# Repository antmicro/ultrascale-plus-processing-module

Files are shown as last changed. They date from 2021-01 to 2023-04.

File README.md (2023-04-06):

# Antmicro UltraScale+ Processing Module

Copyright (c) 2016-2023 [Antmicro](https://www.antmicro.com)



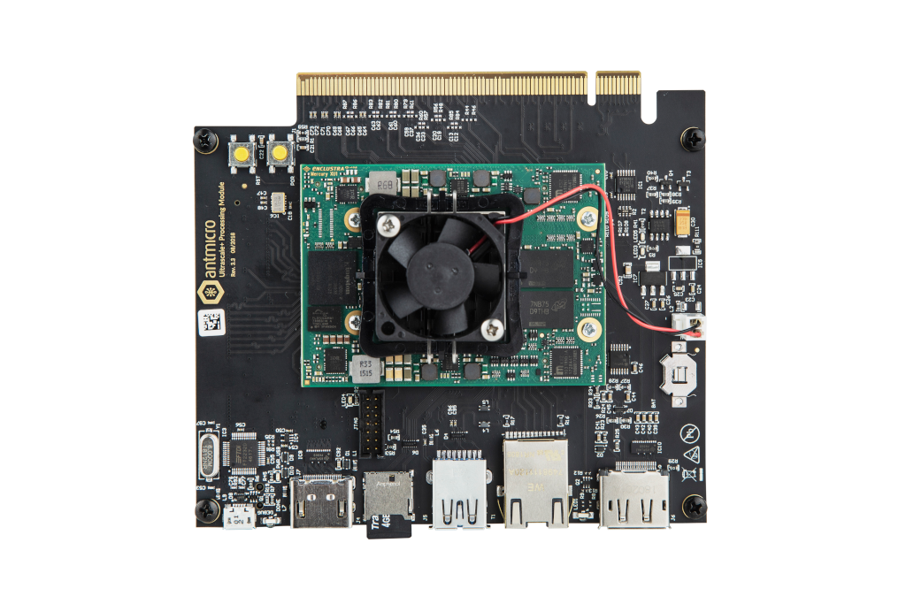
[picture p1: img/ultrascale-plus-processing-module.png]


## Overview

Antmicro’s Ultrascale+ Processing Module is a specialized development board supporting Enclustra [Mercury+ XU1 module](https://www.enclustra.com/en/products/system-on-chip-modules/mercury-xu1) with an embedded Xilinx Zynq UltraScale+ FPGA MPSoC, created for high-speed data processing applications.
The UltraScale+ Processing Module is an excellent starting point for developing your next generation FPGA MPSoC product in machine vision, image acquisition & processing, industrial motion control and other applications.

## Project structure

The main directory contains the Altium PCB project file, the Outjob file, LICENSE and README.
The remaining files are stored in the following directories:

* `PCB` -  contains all Altium design files
* `Libraries` - contains the component libraries
* `Documentation` - contains selected files for device fabrication (schematic in PDF, BoM) generated from the Altium project
* `img` - contains graphics for this README
* `3DModels` - contains files defining the mechanical model of the assembled board

The PCB project files were prepared in Altium Designer 14.1.

## Key Features

* Enclustra Mercury+ module connector
* 28 differential pairs available on the edge backplane connector
* 48 differential pairs available on the board-to-board Samtec QSE expansion connector
* DisplayPort as the default video output from the system
* FPGA-driven HDMI output display interface
* MicroSD card slot
* USB 3.0 host interface
* Gigabit Ethernet
* DisplayPort output video interface
* 14-pin JTAG interface

Please note that the backplane connector available on board is not pin-compatible with PCIe x16 standard.

## Getting started

The board can be produced and assembled using the provided design files.
Please take a look at the mechanical layers for more information regarding the PCB stackup recommended for fabrication.
The board should be powered by a 12V DC power supply. 
It is recommended to use the USB debug console interface of the UltraScale+ Processing Module for the first boot.
Use a micro-USB cable to connect the board to your PC.
The board has a built-in dual channel USB/UART converter which is USB bus powered.
Two new serial devices should appear in your system.
One of them, designated with the lower number (/dev/ttyUSB0) is used as a debug console whereas the other (/dev/ttyUSB1) is a general purpose UART connected to the FPGA fabric.
Use your favourite terminal client (e.g. minicom) to open the debug console interface port. The default connection baudrate is 115200 with 8-bit transmission, 1 stop bit and no flow control.

## License

This project is published under the [Apache-2.0](LICENSE).

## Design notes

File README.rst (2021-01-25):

Antmicro UltraScale+ Processing Module
======================================

Copyright (c) 2016-2021 `Antmicro <https://www.antmicro.com/>`_

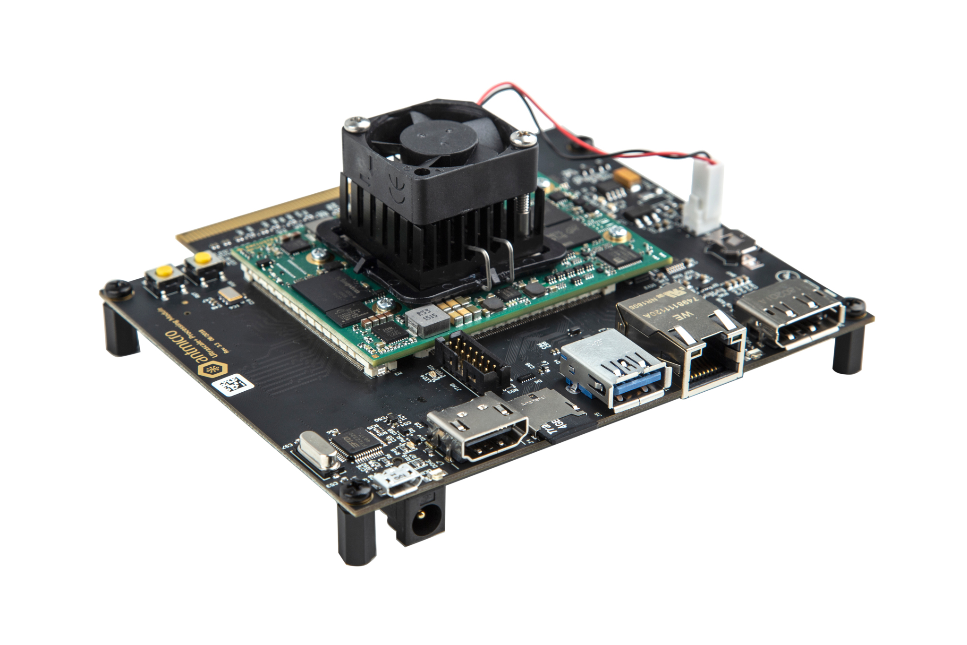
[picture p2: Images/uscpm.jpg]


Overview
========

Antmicro’s Ultrascale+ Processing Module is a specialized development board supporting Enclustra `Mercury+ XU1 module <https://www.enclustra.com/en/products/system-on-chip-modules/mercury-xu1/>`_ with an embedded Xilinx Zynq UltraScale+ FPGA MPSoC, created for high-speed data processing applications.
The UltraScale+ Processing Module is an excellent starting point for developing your next generation FPGA MPSoC product in machine vision, image acquisition & processing, industrial motion control and other applications.

Repository structure:
---------------------

The main repository directory contains the Altium PCB project file, the Outjob file, LICENSE and README.
The remaining files are stored in the following directories:

* ``PCB`` -  contains all Altium design files
* ``Libraries`` - contains the component libraries
* ``Documentation`` - contains selected files for device fabrication (schematic in PDF, BoM) generated from the Altium project
* ``Images`` - contains graphics for this README
* ``3DModels`` - contains files defining the mechanical model of the assembled board

The PCB project files were prepared in Altium Designer 14.1.

Key Features
============

* Enclustra Mercury+ module connector
* 28 differential pairs available on the edge backplane connector
* 48 differential pairs available on the board-to-board Samtec QSE expansion connector
* DisplayPort as the default video output from the system
* FPGA-driven HDMI output display interface
* MicroSD card slot
* USB 3.0 host interface
* Gigabit Ethernet
* DisplayPort output video interface
* 14-pin JTAG interface

Please note that the backplane connector available on board is not pin-compatible with PCIe x16 standard.

Board layout & dimensions
=========================

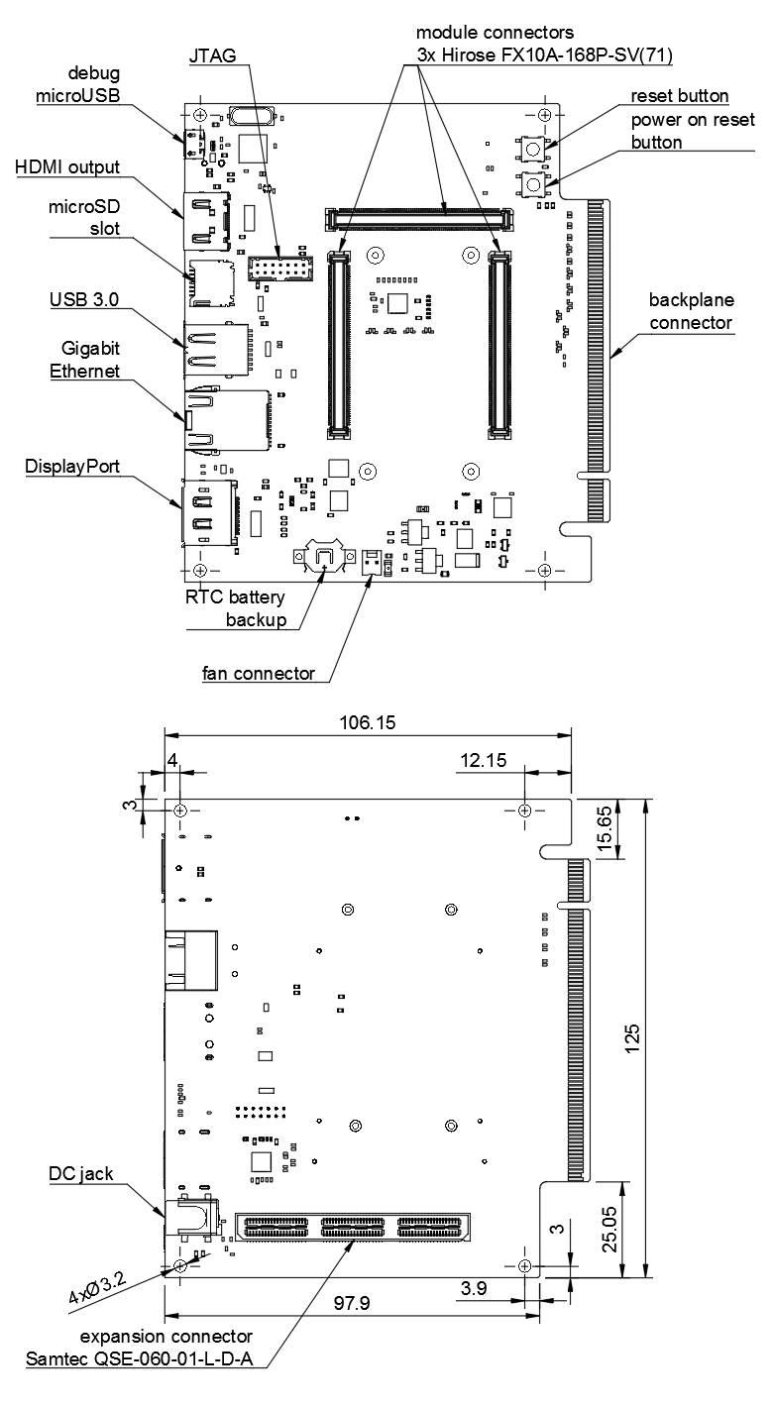
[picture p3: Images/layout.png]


Getting started
===============

The board can be produced and assembled using the provided design files.
Please take a look at the mechanical layers for more information regarding the PCB stackup recommended for fabrication.
The board should be powered by a 12V DC power supply. 
It is recommended to use the USB debug console interface of the UltraScale+ Processing Module for the first boot.
Use a micro-USB cable to connect the board to your PC.
The board has a built-in dual channel USB/UART converter which is USB bus powered.
Two new serial devices should appear in your system.
One of them, designated with the lower number (/dev/ttyUSB0) is used as a debug console whereas the other (/dev/ttyUSB1) is a general purpose UART connected to the FPGA fabric.
Use your favourite terminal client (e.g. minicom) to open the debug console interface port. The default connection baudrate is 115200 with 8-bit transmission, 1 stop bit and no flow control.

License
=======

`Apache-2.0 <LICENSE>`_

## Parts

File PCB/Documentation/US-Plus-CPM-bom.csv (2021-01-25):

Designator | PartNumber | Value | Description | Manufacturer | MPN | Supplier1 | SupplierPartNumber1 | Quantity
BAT | Keystone_CR1025 | 3030 | SMT holder for CR1025 battery | Keystone |  | Digi-Key | 36-3030-ND | 1
C1, C2, C3, C4, C5, C6, C7, C8, C9, C10, C11, C12, C13, C14, C15, C16, C17, C18, C19, C20, C21, C22, C23, C24, C25, C26, C27, C28, C29, C30, C31, C32, C33, C34, C35, C36, C37, C39, C40, C41, C42, C43, C44, C45, C46, C47, C48, C49, C50, C52, C53, C54, C55, C56, C57, C59, C60, C61, C62, C63, C64, C65, C66, C67, C68, C69, C70, C71, C72, C73, C74, C75, C76, C77, C78, C79, C80, C81, C82, C83, C84, C85, C86, C87, C88, C89, C90, C91, C92, C95, C96, C97, D1, D2, D3, D4, D6, D7, D8, D9, D10, DEBUG, DONE, FAN, FAN2, FAN3, IC1, IC2, IC3, IC4, IC5, IC6, IC7, IC8, IC9, IC10, IC12, IC13, J1, J3, J4, J7, L1, L2, L3, L4, L5, L6, L7, L9, LED1, LED3, LED4, LED5, M1, M2, M3, POR, PWR_USB, Q1, Q2, Q4, R1, R2, R3, R4, R5, R6, R7, R8, R9, R10, R11, R12, R13, R14, R15, R16, R17, R18, R19, R20, R21, R22, R23, R24, R25, R26, R27, R28, R29, R30, R31, R32, R33, R34, R35, R36, R37, R38, R39, R40, R41, R42, R43, R44, R45, R46, R47, R48, R49, R50, R51, R52, R53, R54, R55, R56, R57, R58, R59, R60, R61, R62, R63, R64, R65, R66, R67, R68, R69, R70, R71, R72, R73, R74, R75, R76, R77, R78, R79, R80, R81, R82, R83, R84, R85, R86, R87, R88, R89, R90, R91, R92, R93, R94, RA1, RST, SP1, SP2, SP3, SP4, T1, T2, T3, Y1, Z1, Z2, Z3, Z4 |  | 100n, 100n, 100n, 100n, 100n, 100n, 100n, 100n, 100n, 100n, 100n, 100n, 100n, 100n, 1u, 100n, 100n, 100n, 100n, 100n, 100n, 100n, 47u, 4u7, 4u7, 4u7, 4u7, 100n, 100n, 22u, 100n, 100n, 100n, 100n, 100n, 100n, 100n, 100n, 100n, 100n, 100n, 100n, 100n, 100n, 100n, 100n, 100n, 100n, 100n, 100u, 18p, 100n, 100n, 100n, 100n, 100n, 100n, 100n, 100n, 100n, 100n, 100n, 100n, 100n, 100n, 100n, 100n, 100n, 100n, 100n, 100n, 100n, 10n, 47p, 47p, 100n, 100n, 100n, 100n, 100n, 100n, 100n, 100n, 100n, 100n, 100n, 100n, 100n, 1u, 100n, 100n, 18p, 1N4148WS, 1N4148WS, TPD6E05U06, TPD6E05U06, TPD6E05U06, TPD4E05U06, TPD4E05U06, 1N4148WS, 1N4148WS, Molex 47346-0001, KPBA-3010SURKMGKC, [NoValue], MOLEX_2201-2021, MOLEX_008650805, NTS0104PW, PTN3363BSMP, FT2232D, TLV70033DCKT, AP1117E50G-13, EG-2102CB, AP1117E50G-13, TPD8S009, PTN3363BSMP, TPD8S009, NTS0104PW, FIN1019MTCX, [NoParam], 694106106102, 114-00841-68, [NoValue], BLM18SG121TN1D, BLM18EG221SN1D, DLW21SN900SQ2, DLW21SN900SQ2, DLW21SN900SQ2, BLM18SG121TN1D, BLM18SG121TN1D, BLM18SG121TN1D, KPBA-3010SURKMGKC, KPT-1608SGC, KPT-1608SGC, KPT-1608SGC, FX10A-168P-SV(71), FX10A-168P-SV(71), FX10A-168P-SV(71), B3S-100X, KPT-1608SGC, PMGD780SN, PMGD780SN, PMV32UP, 10k, 22R, 470R, 10k, 10k, 330R, 330R, 330R, 330R, 0R, 0R, 10k, 10k, 0R, 0R, 150R, 150R, 0R, 10k, 10k, 330R, 10k, 0R, 10R, 100k, 100k, 50R, 50R, 0R, 100k, 1M, 1M, 2k49, 1k5, 22R, 470R, 100k, 100k, 100k, 100R, 470R, 10k, 10k, 0R, 470R, 0R, 10k, 0R, 10k, 10k, 10k, 10k, 0R, 22R, 0R, 0R, 0R, 0R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 | MLCC SMT Capacitor 100nF 0402, MLCC SMT Capacitor 100nF 0402, MLCC SMT Capacitor 100nF 0402, MLCC SMT Capacitor 100nF 0402, MLCC SMT Capacitor 100nF 0402, MLCC SMT Capacitor 100nF 0402, MLCC SMT Capacitor 100nF 0402, MLCC SMT Capacitor 100nF 0402, MLCC SMT Capacitor 100nF 0402, MLCC SMT Capacitor 100nF 0402, MLCC SMT Capacitor 100nF 0603, MLCC SMT Capacitor 100nF 0402, MLCC SMT Capacitor 100nF 0402, MLCC SMT Capacitor 100nF 0603, MLCC SMT Capacitor 1uF 0603, MLCC SMT Capacitor 100nF 0402, MLCC SMT Capacitor 100nF 0402, MLCC SMT Capacitor 100nF 0402, MLCC SMT Capacitor 100nF 0402, MLCC SMT Capacitor 100nF 0402, MLCC SMT Capacitor 100nF 0603, MLCC SMT Capacitor 100nF 0603, MLCC SMT Capacitor 47uF 1206, MLCC SMT Capacitor 4u7F 0603, MLCC SMT Capacitor 4u7F 0603, MLCC SMT Capacitor 4u7F 0603, MLCC SMT Capacitor 4u7F 0603, MLCC SMT Capacitor 100nF 0603, MLCC SMT Capacitor 100nF 0603, Tantalum SMT Capacitor 22uF Case KEMET_C, MLCC SMT Capacitor 100nF 0402, MLCC SMT Capacitor 100nF 0402, MLCC SMT Capacitor 100nF 0402, MLCC SMT Capacitor 100nF 0402, MLCC SMT Capacitor 100nF 0402, MLCC SMT Capacitor 100nF 0402, MLCC SMT Capacitor 100nF 0402, MLCC SMT Capacitor 100nF 0603, MLCC SMT Capacitor 100nF 0603, MLCC SMT Capacitor 100nF 0603, MLCC SMT Capacitor 100nF 0603, MLCC SMT Capacitor 100nF 0603, MLCC SMT Capacitor 100nF 0603, MLCC SMT Capacitor 100nF 0603, MLCC SMT Capacitor 100nF 0603, MLCC SMT Capacitor 100nF 0402, MLCC SMT Capacitor 100nF 0402, MLCC SMT Capacitor 100nF 0603, MLCC S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 | MULTICOMP, MULTICOMP, MULTICOMP, MULTICOMP, MULTICOMP, MULTICOMP, MULTICOMP, MULTICOMP, MULTICOMP, MULTICOMP, WALSIN, MULTICOMP, MULTICOMP, WALSIN, MULTICOMP, MULTICOMP, MULTICOMP, MULTICOMP, MULTICOMP, MULTICOMP, WALSIN, WALSIN, MURATA, MULTICOMP, MULTICOMP, MULTICOMP, MULTICOMP, WALSIN, WALSIN, KEMET, MULTICOMP, MULTICOMP, MULTICOMP, MULTICOMP, MULTICOMP, MULTICOMP, MULTICOMP, WALSIN, WALSIN, WALSIN, WALSIN, WALSIN, WALSIN, WALSIN, WALSIN, MULTICOMP, MULTICOMP, WALSIN, MULTICOMP, MURATA, KEMET, MULTICOMP, MULTICOMP, MULTICOMP, MULTICOMP, MULTICOMP, MULTICOMP, MULTICOMP, MULTICOMP, MULTICOMP, MULTICOMP, MULTICOMP, MULTICOMP, MULTICOMP, MULTICOMP, MULTICOMP, MULTICOMP, MULTICOMP, MULTICOMP, MULTICOMP, MULTICOMP, MULTICOMP, AVX, KEMET, KEMET, MULTICOMP, MULTICOMP, MULTICOMP, WALSIN, WALSIN, MULTICOMP, MULTICOMP, MULTICOMP, MULTICOMP, MULTICOMP, MULTICOMP, MULTICOMP, MULTICOMP, MULTICOMP, MULTICOMP, MULTICOMP, KEMET, MULTICOMP, MULTICOMP, Texas Instruments, Texas Instruments, Texas Instruments, Texas Instruments, Texas Instruments, MULTICOMP, MULTICOMP, Molex, Kingbright, [NoValue], MOLEX, MOLEX, NXP, NXP, FTDI, TEXAS INSTRUMENTS, Diodes, Epson, Diodes, TEXAS INSTRUMENTS, NXP, TEXAS INSTRUMENTS, NXP, OM SEMICONDUCTOR, [NoParam], WURTH ELEKTRONIK, AMPHENOL COMMERCIAL PRODUCTS, MOLEX, MURATA, MURATA, MURATA, MURATA, MURATA, MURATA, MURATA, MURATA, Kingbright, KINGBRIGHT, KINGBRIGHT, KINGBRIGHT, Hirose, Hirose, Hirose, OMRON, KINGBRIGHT, NXP, NXP, NXP, BOURNS, BOURNS, BOURNS, MU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 |  |  |  | 250
FAN1 | molex_2223-2021 | MX-22-23-2021 | Pinhead connector with key | Molex | 022232021 A-6373-02A222 | TME | MX-22-23-2021 | 1
J2 | QSE-060-01-L-D-A | QSE-060-01-L-D-A | SAMTEC QSE-60-01-L-D-A Stacking Board Connector, Dual Row, QSE Series, Receptacle, 0.8 m, 120 Contacts, Surface Mount | SAMTEC | QSE-060-01-L-D-A | Farnell | 1667872 | 1
J5 | WE_692122030100 | 692122030100 |  | WURTH ELEKTRONIK | 692122030100 | Farnell | 1861255 | 1
J6 | CON-Molex-047272-0001 | 0472720001 |  | Molex | 0472720001 | Digi-Key | WM19271CT-ND | 1
JTAG | CON-Molex-87831-1420 | Molex-87831-1420 | HEADER, SQUARE PIN, M/GRID, 14WAY | MOLEX | 87831-1420 | Farnell | 7472285 | 1
R95, R96, R97, R98, R99, R100, R101, R102, R103, R104, R105, R106, R107, R108, R109, R110 | R_0R_0402 | 0R | SMT Resistor 0402 | MULTICOMP |  | Farnell | 2072513 | 16
R111 | R_0R_0805 | 0R | SMT Resistor 0R 0805 | VISHAY |  | Farnell | 1469846 | 1

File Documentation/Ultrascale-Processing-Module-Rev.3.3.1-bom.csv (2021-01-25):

Designator | Quantity | Value | Footprint | Manufacturer | MPN
J4 | 1 | 114-00841-68 | 114-00841-68 | AMPHENOL COMMERCIAL PRODUCTS | 114-00841-68
C76 | 1 | 10n | 0603 | AVX | 06031C103JAT2A
R1, R19, R52 | 3 | 10k | 0603 | BOURNS | CR0603-JW-103ELF
R18, R23, R29, R53, R55, R58, R59, R111 | 8 | 0R | 0603 | BOURNS | CR0603-J/-000ELF
R2 | 1 | 22R | BOURNS-CAY16-J4 | BOURNS | CAY16-220J4LF
R25, R37, R38, R39 | 4 | 100k | 0603 | BOURNS | CR0603-JW-104GLF
R26, R30 | 2 | 100k | 0603 | BOURNS | CR0603-FX-1003HLF
R3, R41, R45 | 3 | 470R | 0603 | BOURNS | CR0603-JW-471GLF
R31, R32 | 2 | 1M | 0603 | BOURNS | CR0603-JW-105GLF
R54 | 1 | 22R | 0603 | BOURNS | CR0603-JW-220GLF
R6, R7, R21 | 3 | 330R | 0603 | BOURNS | CR0603-FX-3300GLF
IC7 | 1 | AP1117E50G-13 | SOT223 | Diodes | AP1117E50G-13
IC6 | 1 | EG-2102CB | EG-2102CB | Epson | EG-2102CB 156.2500M-LGPAL3
IC3 | 1 | FT2232D | LQFP-48 | FTDI | FT2232D-REEL
M1, M2, M3 | 3 | FX10A-168P-SV(71) | HIROSE_FX10A-168P-SV(71) | Hirose | FX10A-168P-SV(71)
Y1 | 1 | LFXTAL026900 | crystal_smd | IQD FREQUENCY PRODUCTS | LFXTAL026900
C30 | 1 | 22u | KEMET_C | KEMET | T491C226K025AT
C53, C97 | 2 | 18p | 0402 | KEMET | C0402C180J5GACAUTO
C77, C78 | 2 | 47p | 0402 | KEMET | C0402C470J5GACTU
BAT | 1 | 3030 | KEYSTONE_CR1025 | Keystone | 3030
DONE, LED1 | 2 | KPBA-3010SURKMGKC | 3010SURKMGKC | Kingbright | KPBA-3010SURKMGKC
LED3, LED4, LED5, PWR_USB | 4 | KPT-1608SGC | LED0603 | KINGBRIGHT | KPT-1608SGC
DEBUG | 1 | Molex 47346-0001 | CON-Molex-047346-0001 | Molex | 473460001
FAN1 | 1 | MX-22-23-2021 | molex_2223-2021 | Molex | 022232021 A-6373-02A222
J6 | 1 | 0472720001 |  | Molex | 0472720001
J7 | 1 |  | Molex_HDMI_471511001 | MOLEX | 47151-1001
JTAG | 1 | Molex-87831-1420 | CON-Molex-87831-1420 | MOLEX | 87831-1420
C1, C2, C3, C4, C5, C6, C7, C8, C9, C10, C16, C17, C18, C31, C32, C34, C35, C47, C48, C50, C54, C55, C56, C57, C64, C65, C68, C69, C70, C71, C72, C73, C74, C75, C79, C80, C81, C95, C96 | 39 | 100n | 0402 | MULTICOMP | MC0402X104M100CT
C15, C92 | 2 | 1u | 0603 | MULTICOMP | MC0603X105M6R3CT
C24, C25, C26, C27 | 4 | 4u7 | 0603 | MULTICOMP | MC0603X475K6R3CT
D1, D2, D9, D10 | 4 | 1N4148WS | SOD-323 | MULTICOMP | 1N4148WS
R10, R11, R14, R15, R44, R46, R48, R56, R57, R60, R61, R67, R68, R69, R70, R71, R72, R73, R74, R75, R76, R77, R78, R79, R80, R81, R82, R83, R84, R85, R86, R87, R90, R94, R95, R96, R98, R107, R109 | 39 | 0R | 0402 | MULTICOMP | MCMR04X000 PTL
R16, R17 | 2 | 150R | 0603 | MULTICOMP | MC0063W06031150R
R24 | 1 | 10R | 0603 | MULTICOMP | MCWR06X10R0FTL
R4, R5, R12, R13, R20, R22, R42, R43, R47, R49, R50, R51, R88, R93 | 14 | 10k | 0402 | MULTICOMP | MCMR04X1002FTL
R40 | 1 | 100R | 0603 | MULTICOMP | MC0063W06035100R
R8, R9 | 2 | 330R | 0402 | MULTICOMP | MCMR04X3300FTL
C52 | 1 | 100u | 0805 | MURATA | GRM21BR60J107ME15L
L1, L6, L7, L9 | 4 | BLM18SG121TN1D | 0603 | MURATA | BLM18SG121TN1D
L2 | 1 | BLM18EG221SN1D | 0603 | MURATA | BLM18EG221SN1D
L3, L4, L5 | 3 | DLW21SN900SQ2 | DLW21SN900SQ2 | MURATA | DLW21SN900SQ2L
IC1, IC12 | 2 | NTS0104PW | TSSOP-14 | NXP | NTS0104PW
IC2 | 1 | PTN3363BSMP | QFN-32 | NXP | PTN3363BSMP
Q1, Q2 | 2 | PMGD780SN | SOT-363 | NXP | PMGD780SN,115
Q4 | 1 | PMV32UP | SOT-23 | NXP | PMV32UP
T3 | 1 | BSS138AKA | SOT-23 | NXP | BSS138AKA
IC13 | 1 | FIN1019MTCX | TSSOP-14 | OM SEMICONDUCTOR | FIN1019MTCX
POR, RST | 2 | B3S-100X | B3S-100X | OMRON | B3S-1002
J2 | 1 | QSE-060-01-L-D-A | QSE-060-01-L-D-A | SAMTEC | QSE-060-01-L-D-A
R34 | 1 | 1k5 | 0603 | TE CONNECTIVITY / NEOHM | CPF0603B1K5E1
D3, D4, D6 | 3 | TPD6E05U06 | TPD6E05U06_PASS | Texas Instruments | TPD6E05U06RVZR
D7, D8 | 2 | TPD4E05U06 | TPD4E05U06_PASS | Texas Instruments | TPD4E05U06DQAR
IC4 | 1 | TLV70033DCKT | SC70-5 | TEXAS INSTRUMENTS | TLV70033DCKT
IC8, IC10 | 2 | TPD8S009 | SON-15 | TEXAS INSTRUMENTS | TPD8S009DSMR
R27, R28 | 2 | 50R | 0603 | VISHAY | CRCW060350R0FKEA
R33 | 1 | 2k49 | 0603 | Vishay | CRCW06032K49FKEA
R35, R91 | 2 | 22R | 0402 | VISHAY | CRCW040222R0FKED
R36 | 1 | 470R | 0402 | VISHAY | CRCW0402470RFKED.
R62 | 1 | 12k4 | 0603 | Vishay | CRCW060312K4FKEA
R92 | 1 | 1k54 | 0402 | VISHAY | CRCW04021K54FKED.
T2 | 1 | SI4447DY-T1-E3 | SOIC-SN8_M | VISHAY | SI4447DY-T1-E3
C11, C14, C21, C22, C28, C29, C39, C40, C41, C42, C43, C44, C45, C46, C49 | 15 | 100n | 0603 | WALSIN | 0603B104K500CT
J3 | 1 | 694106106102 | 694106106102 | WURTH ELEKTRONIK | 694106106102
J5 | 1 | 692122030100 | WE_692122030100 | WURTH ELEKTRONIK | 692122030100
SP1, SP2, SP3, SP4 | 4 | 9774040243 | M2-4mm | WURTH ELEKTRONIK | 9774040243R
T1 | 1 | 7498111120R | 7498111120R | WURTH ELEKTRONIK | 7498111120R
RA1 | 1 | 22R | RA_1206 | YAGEO (PHYCOMP) | TC164-JR-0722RL

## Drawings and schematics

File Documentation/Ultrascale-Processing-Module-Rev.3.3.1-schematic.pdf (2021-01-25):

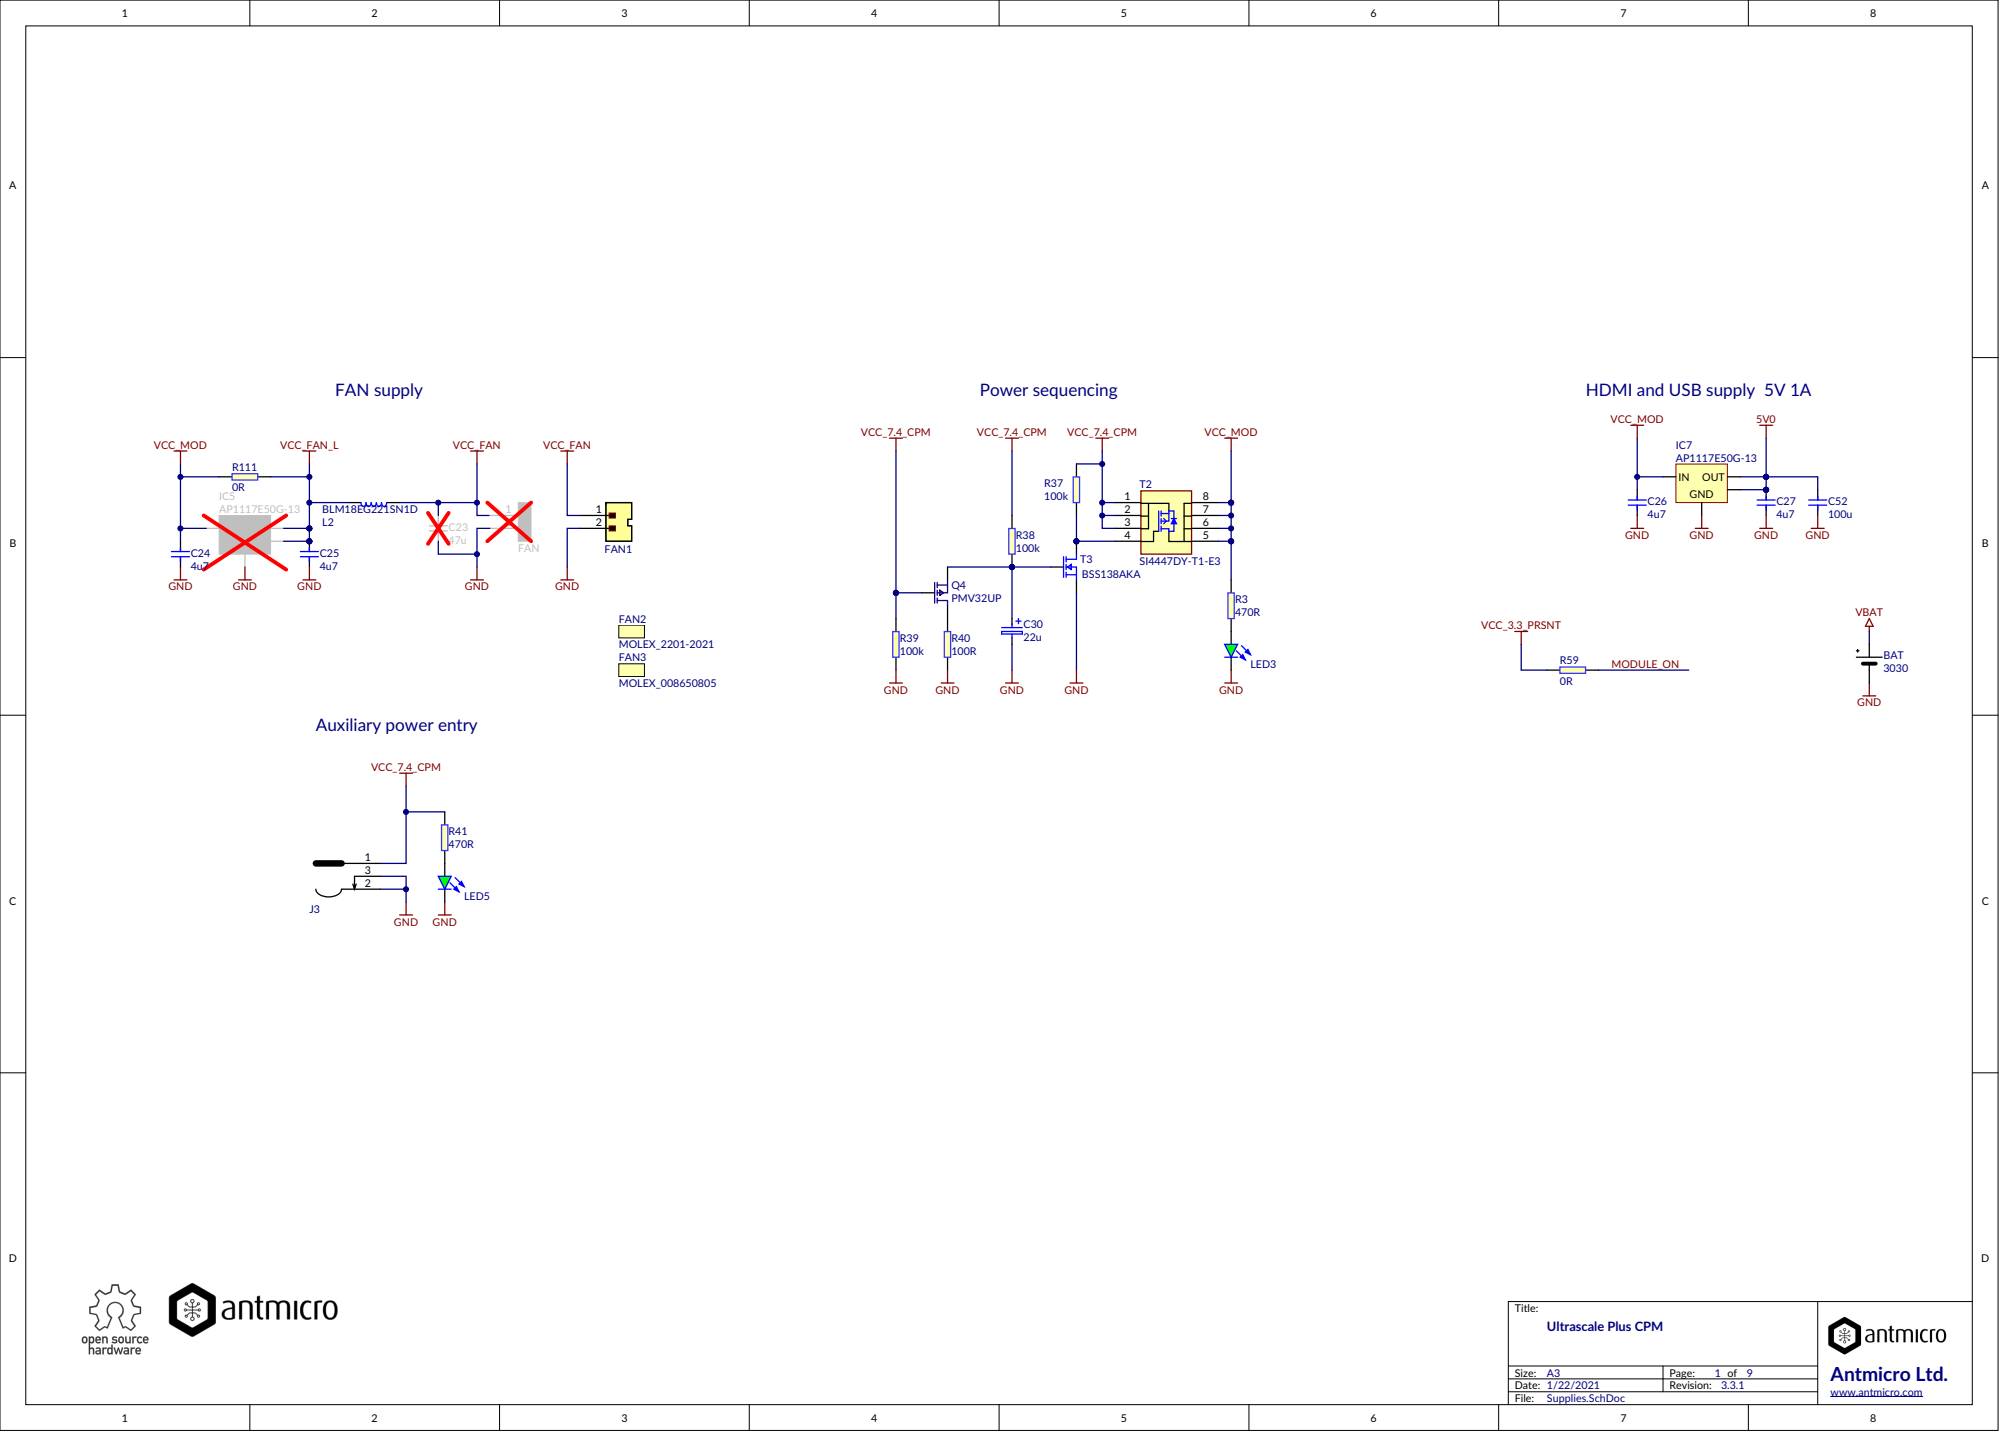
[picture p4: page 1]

Title: Ultrascale Plus CPM

Size: A3 | Page: 1 of | Antmicro Ltd. www.antmicro.com
Date: 1/22/2021 | Revision: 3.3.1

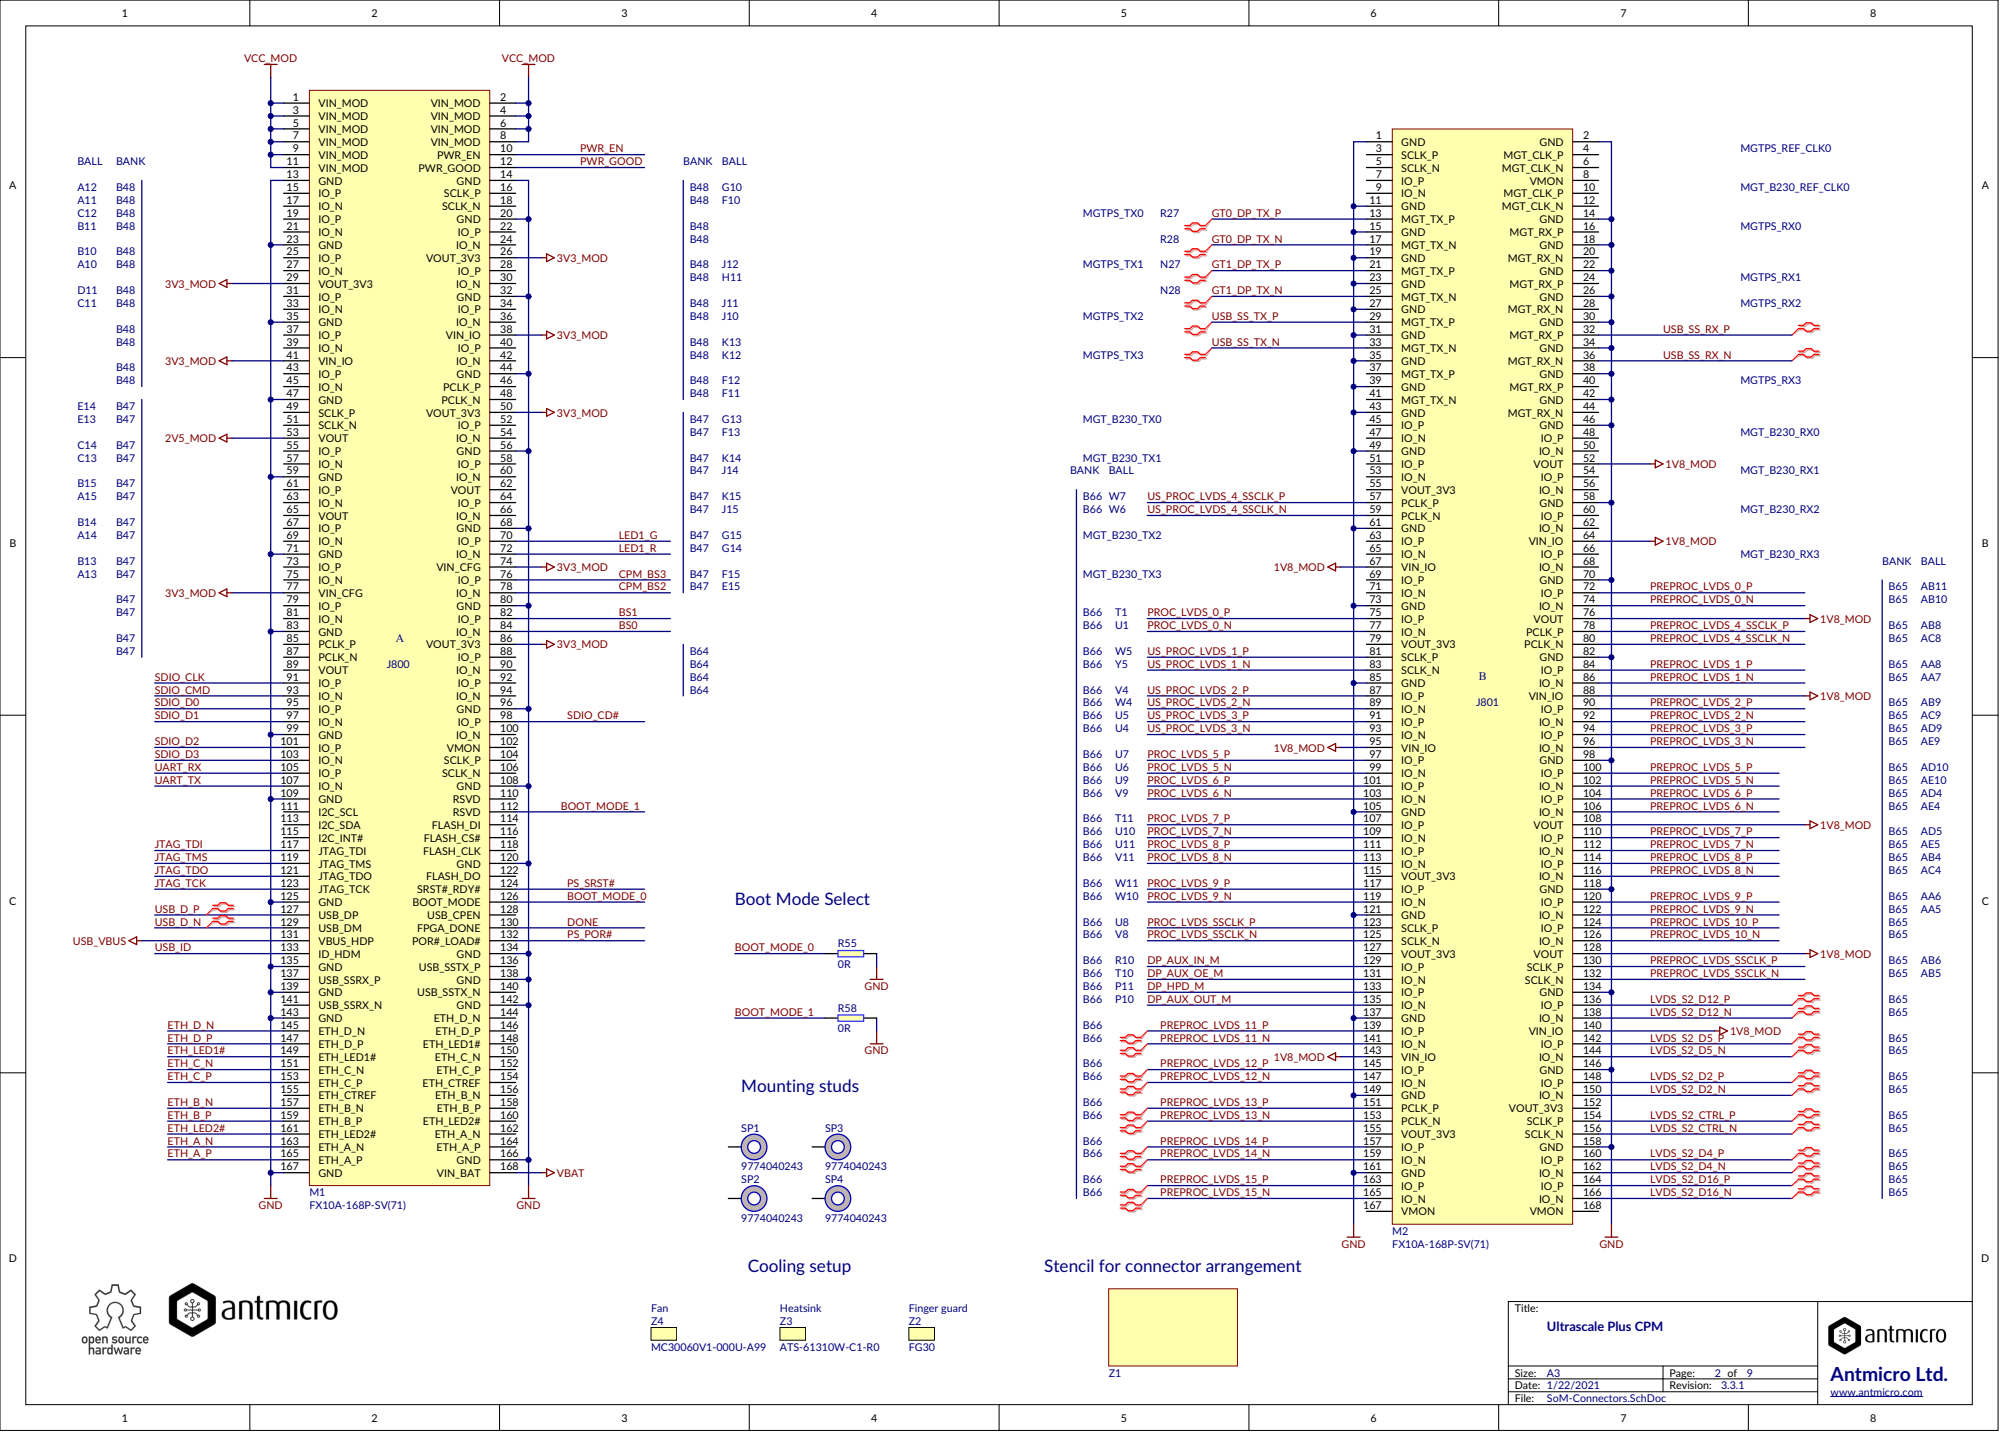
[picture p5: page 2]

IO_P 87 IO_N 89 IO_P 91 IO_N 93 VIN_IO 95

PREPROC_LVDS_2_P PREPROC_LVDS_2_N PREPROC_LVDS_3_P PREPROC_LVDS_3_N PREPROC_LVDS_5_P PREPROC_LVDS_5_N PREPROC_LVDS_6_P PREPROC_LVDS_6_N

IO_P 101 IO_N 103 IO_P 105 IO_N 107 GND 109

IO_P 97 IO_N 99 IO_P 101 IO_N 103 GND 105

I2C_SCL 111

USB_DP 127 USB_DM 129 VBUS_HDP 131

ID_HDM 133 GND 135

USB_SSRX_P 137

USB_SSRX_N 141

Stencil for connector arrangement

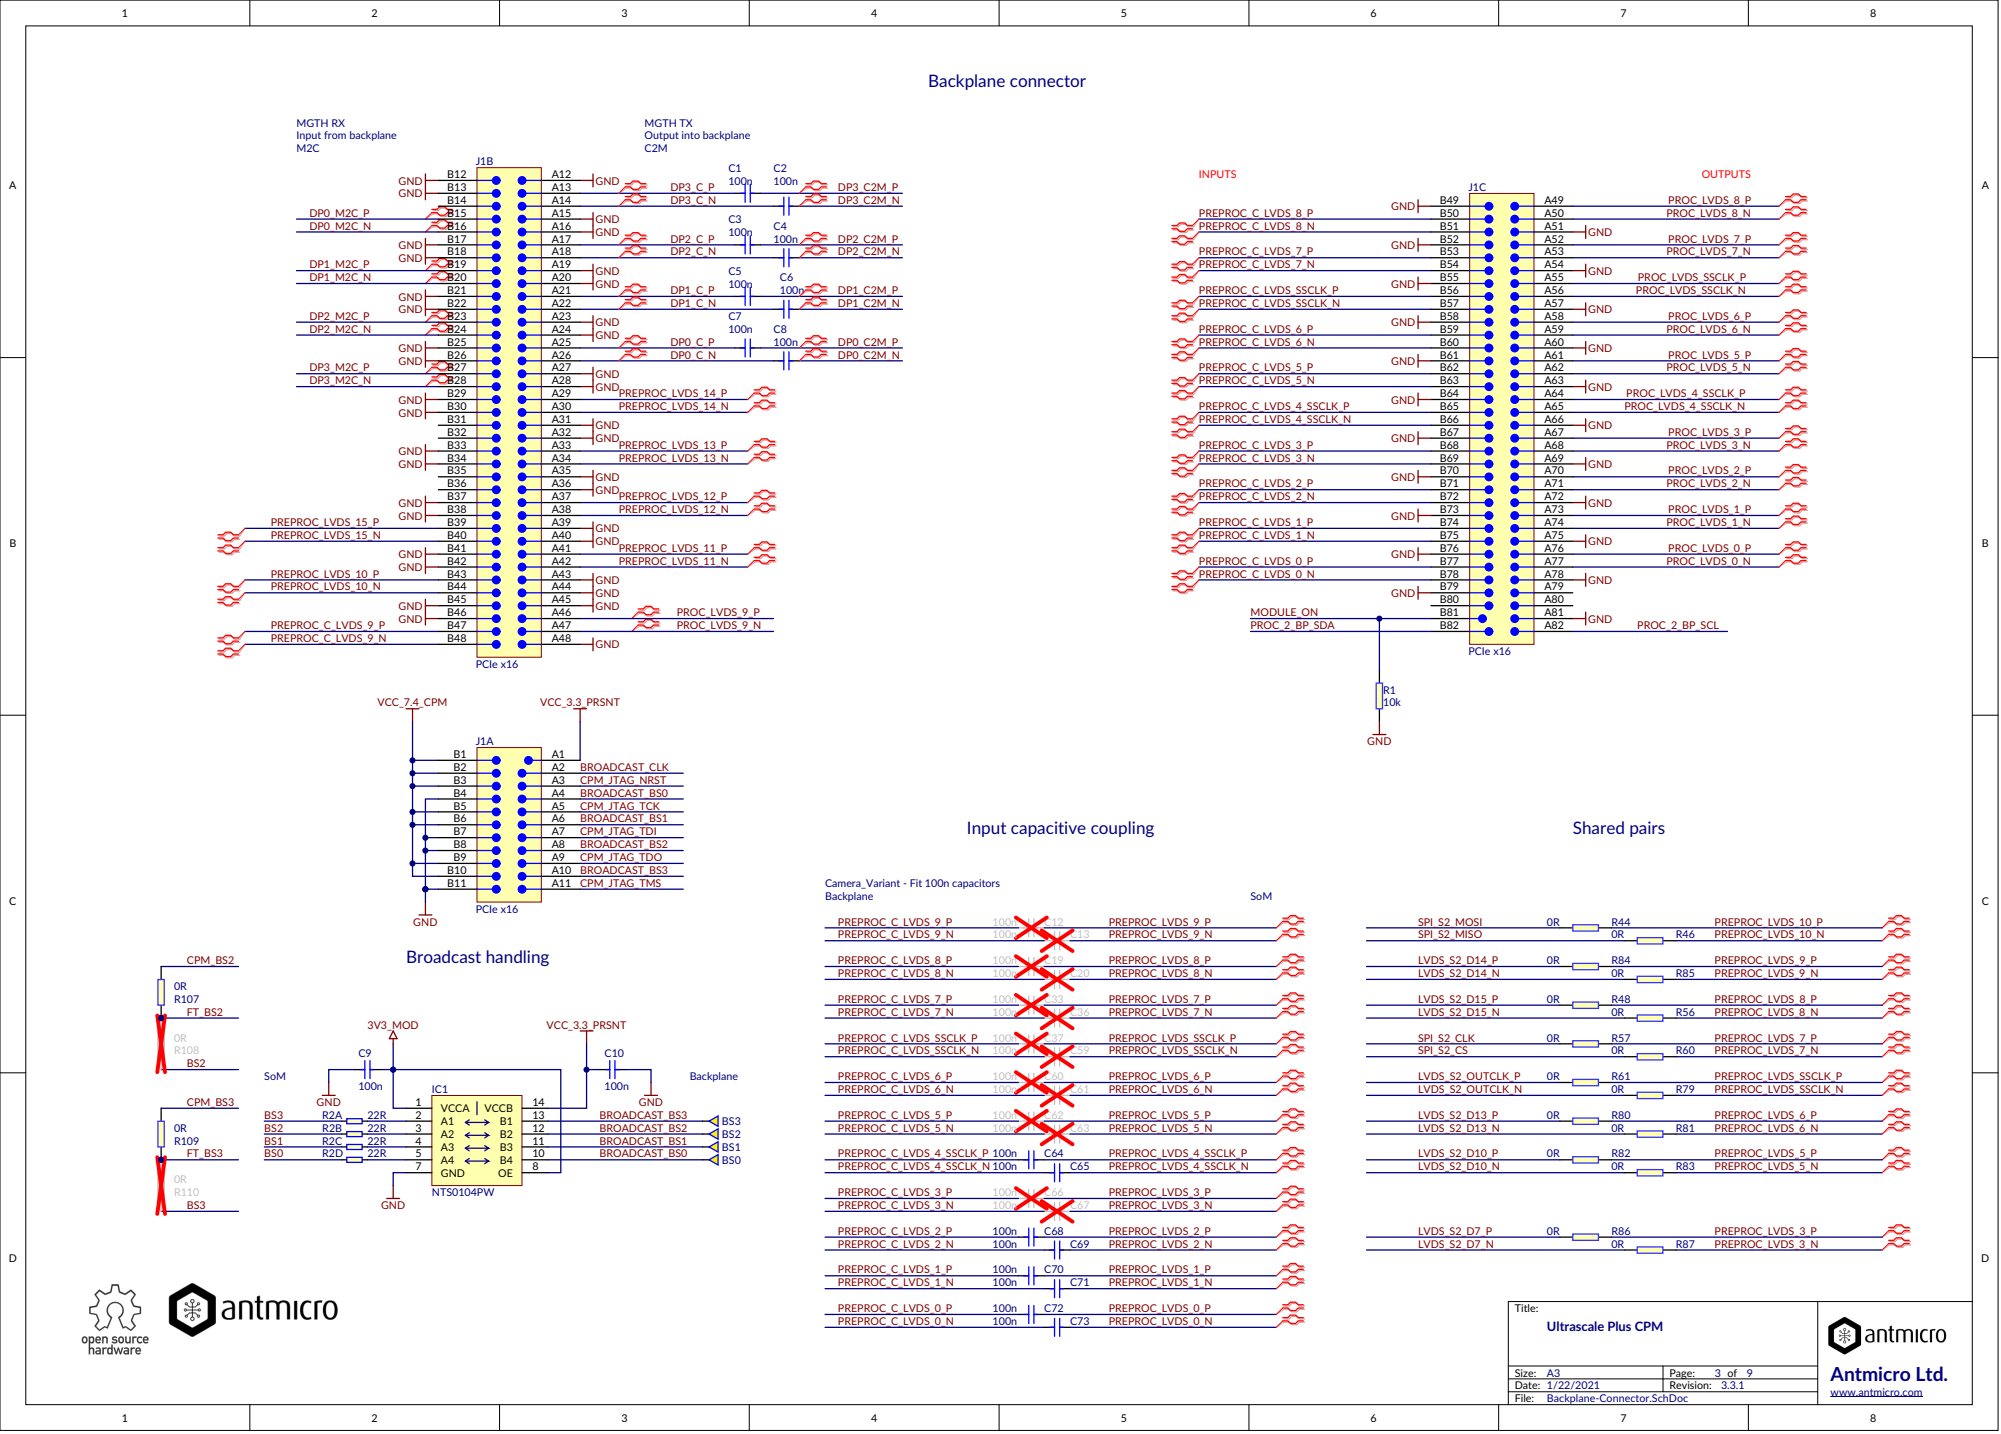
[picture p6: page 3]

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
Title:

A3 | Page: 3 of 9

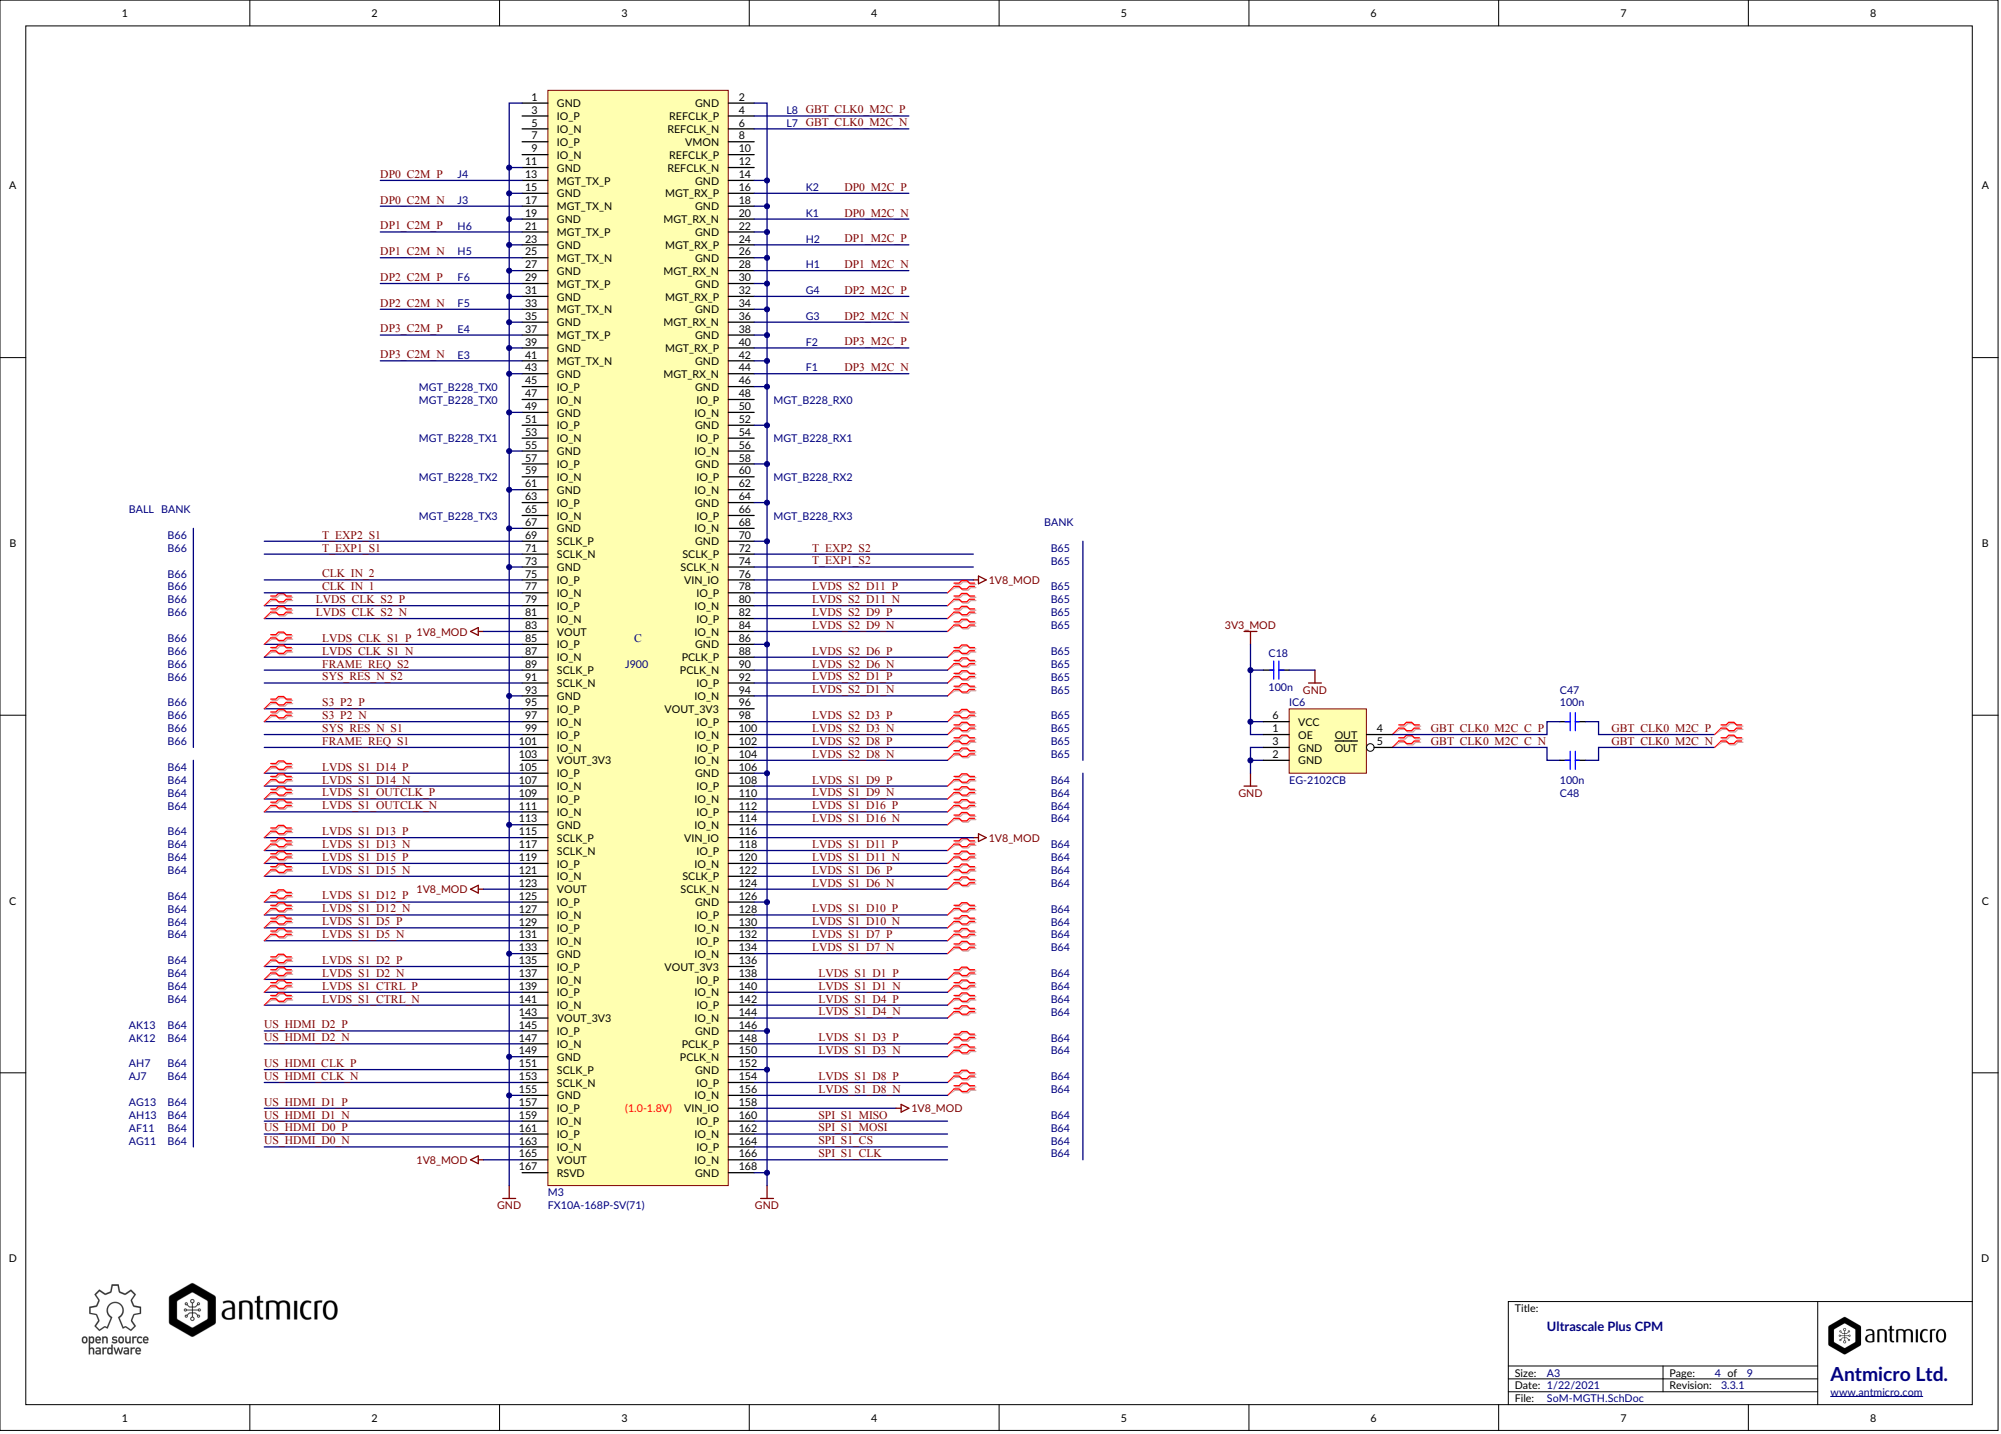
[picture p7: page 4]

MGT_TX_P 13 GND 15

MGT_TX_N 17 GND 19

MGT_TX_P 21 GND 23

MGT_TX_N 25 GND 27

MGT_TX_P 29 GND 31

MGT_TX_N 33 GND 35

MGT_TX_P 37 GND 39

MGT_TX_N 41 GND 43

SCLK_P 69 SCLK_N 71 GND 73

IO_P 75 IO_N 77 IO_P 79 IO_N 81 VOUT 83

IO_P 85 IO_N 87 SCLK_P 89 SCLK_N 91 GND 93

IO_P 95 IO_N 97 IO_P 99 IO_N 101 VOUT_3V3 103

SCLK_P 115 SCLK_N 117 IO_P 119 IO_N 121 VOUT 123

IO_P 125 IO_N 127 IO_P 129 IO_N 131 GND 133

IO_P 135 IO_N 137 IO_P 139 IO_N 141 VOUT_3V3 143

SCLK_P 151 SCLK_N 153 GND 155

IO_P 157 IO_N 159 IO_P 161 IO_N 163 VOUT 165

RSVD 167

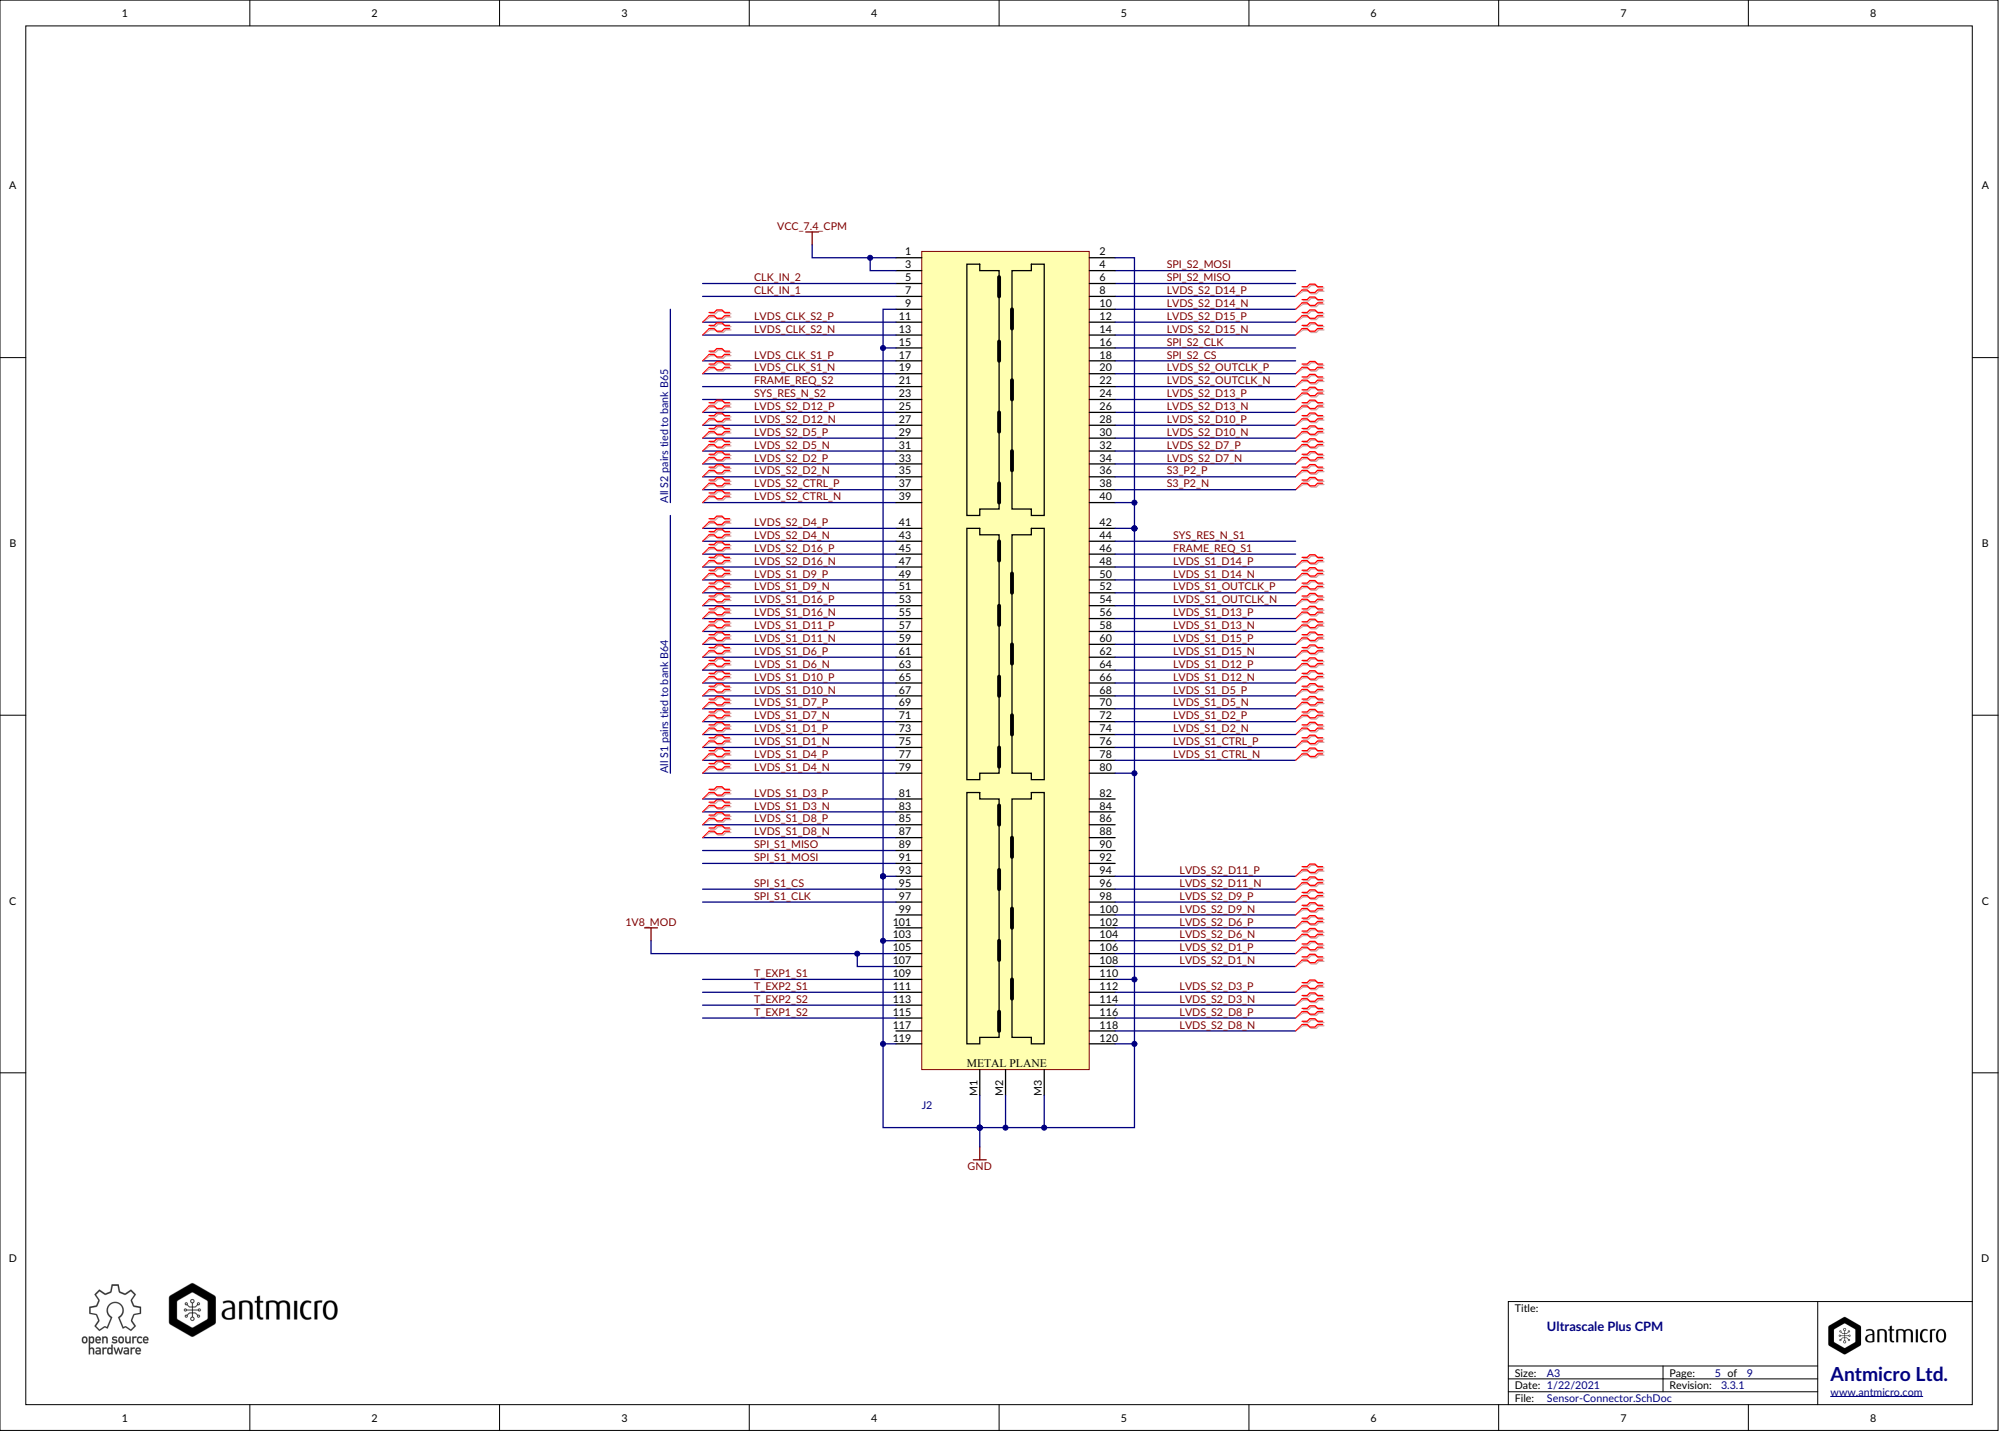
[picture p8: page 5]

All S2 pairs tied to bank B65

42
44 46 48 50 52 54 56 58 60 62 64 66 68 70 72 74 76 78

All S1 pairs tied to bank B64

105
107

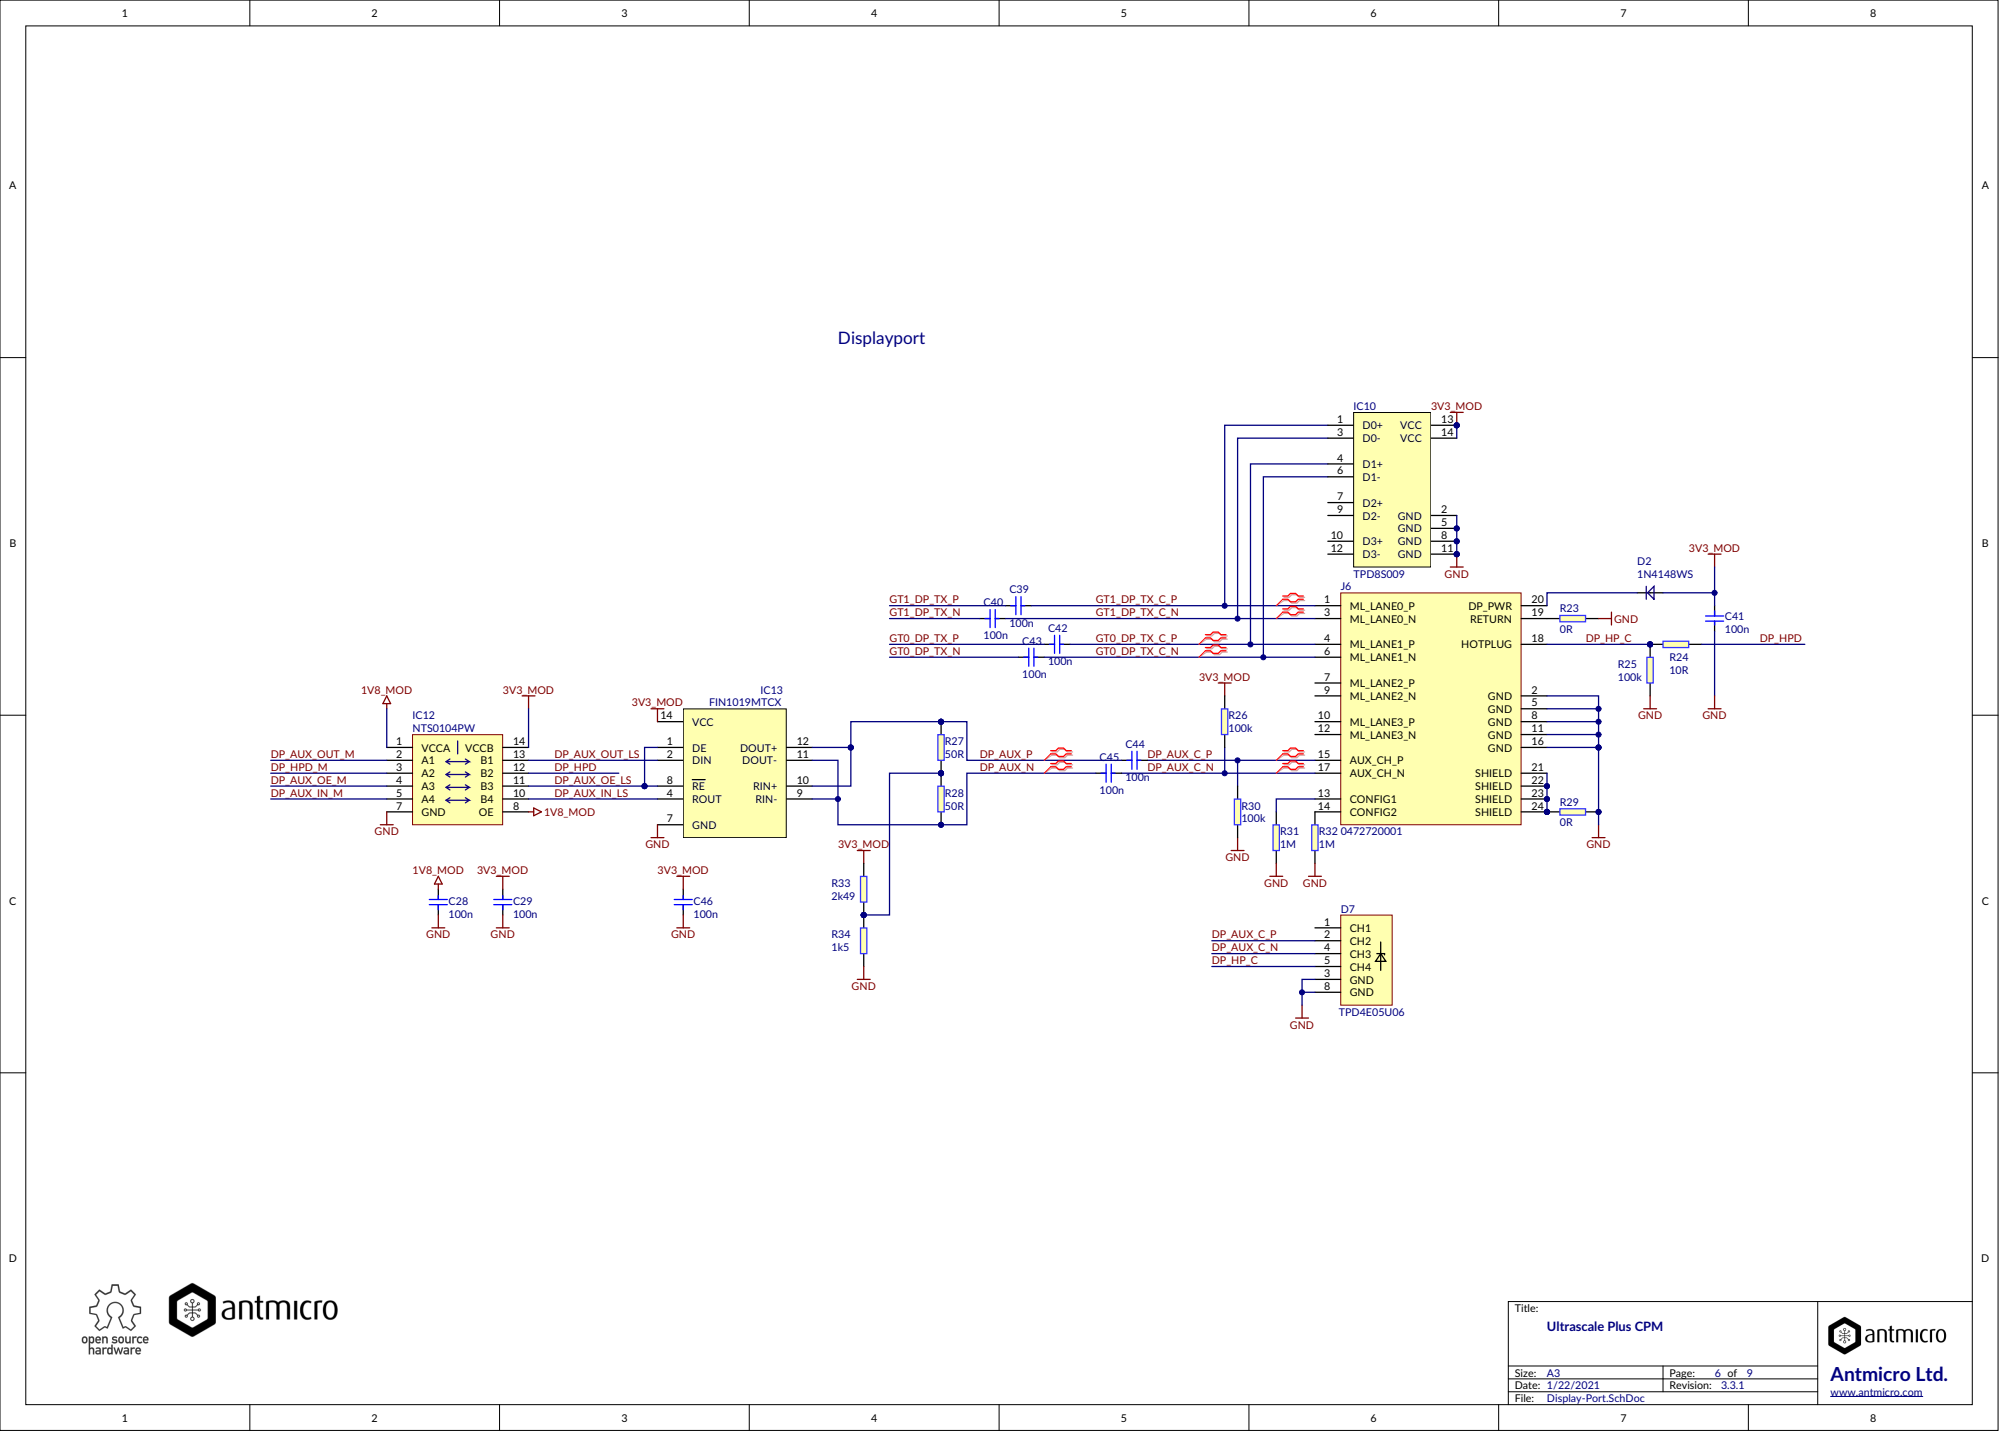
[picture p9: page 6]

D1+ 4
D1- 6

ML_LANE0_N 3 | R23

ML_LANE1_P 4 | DP_HP_C

GND 8

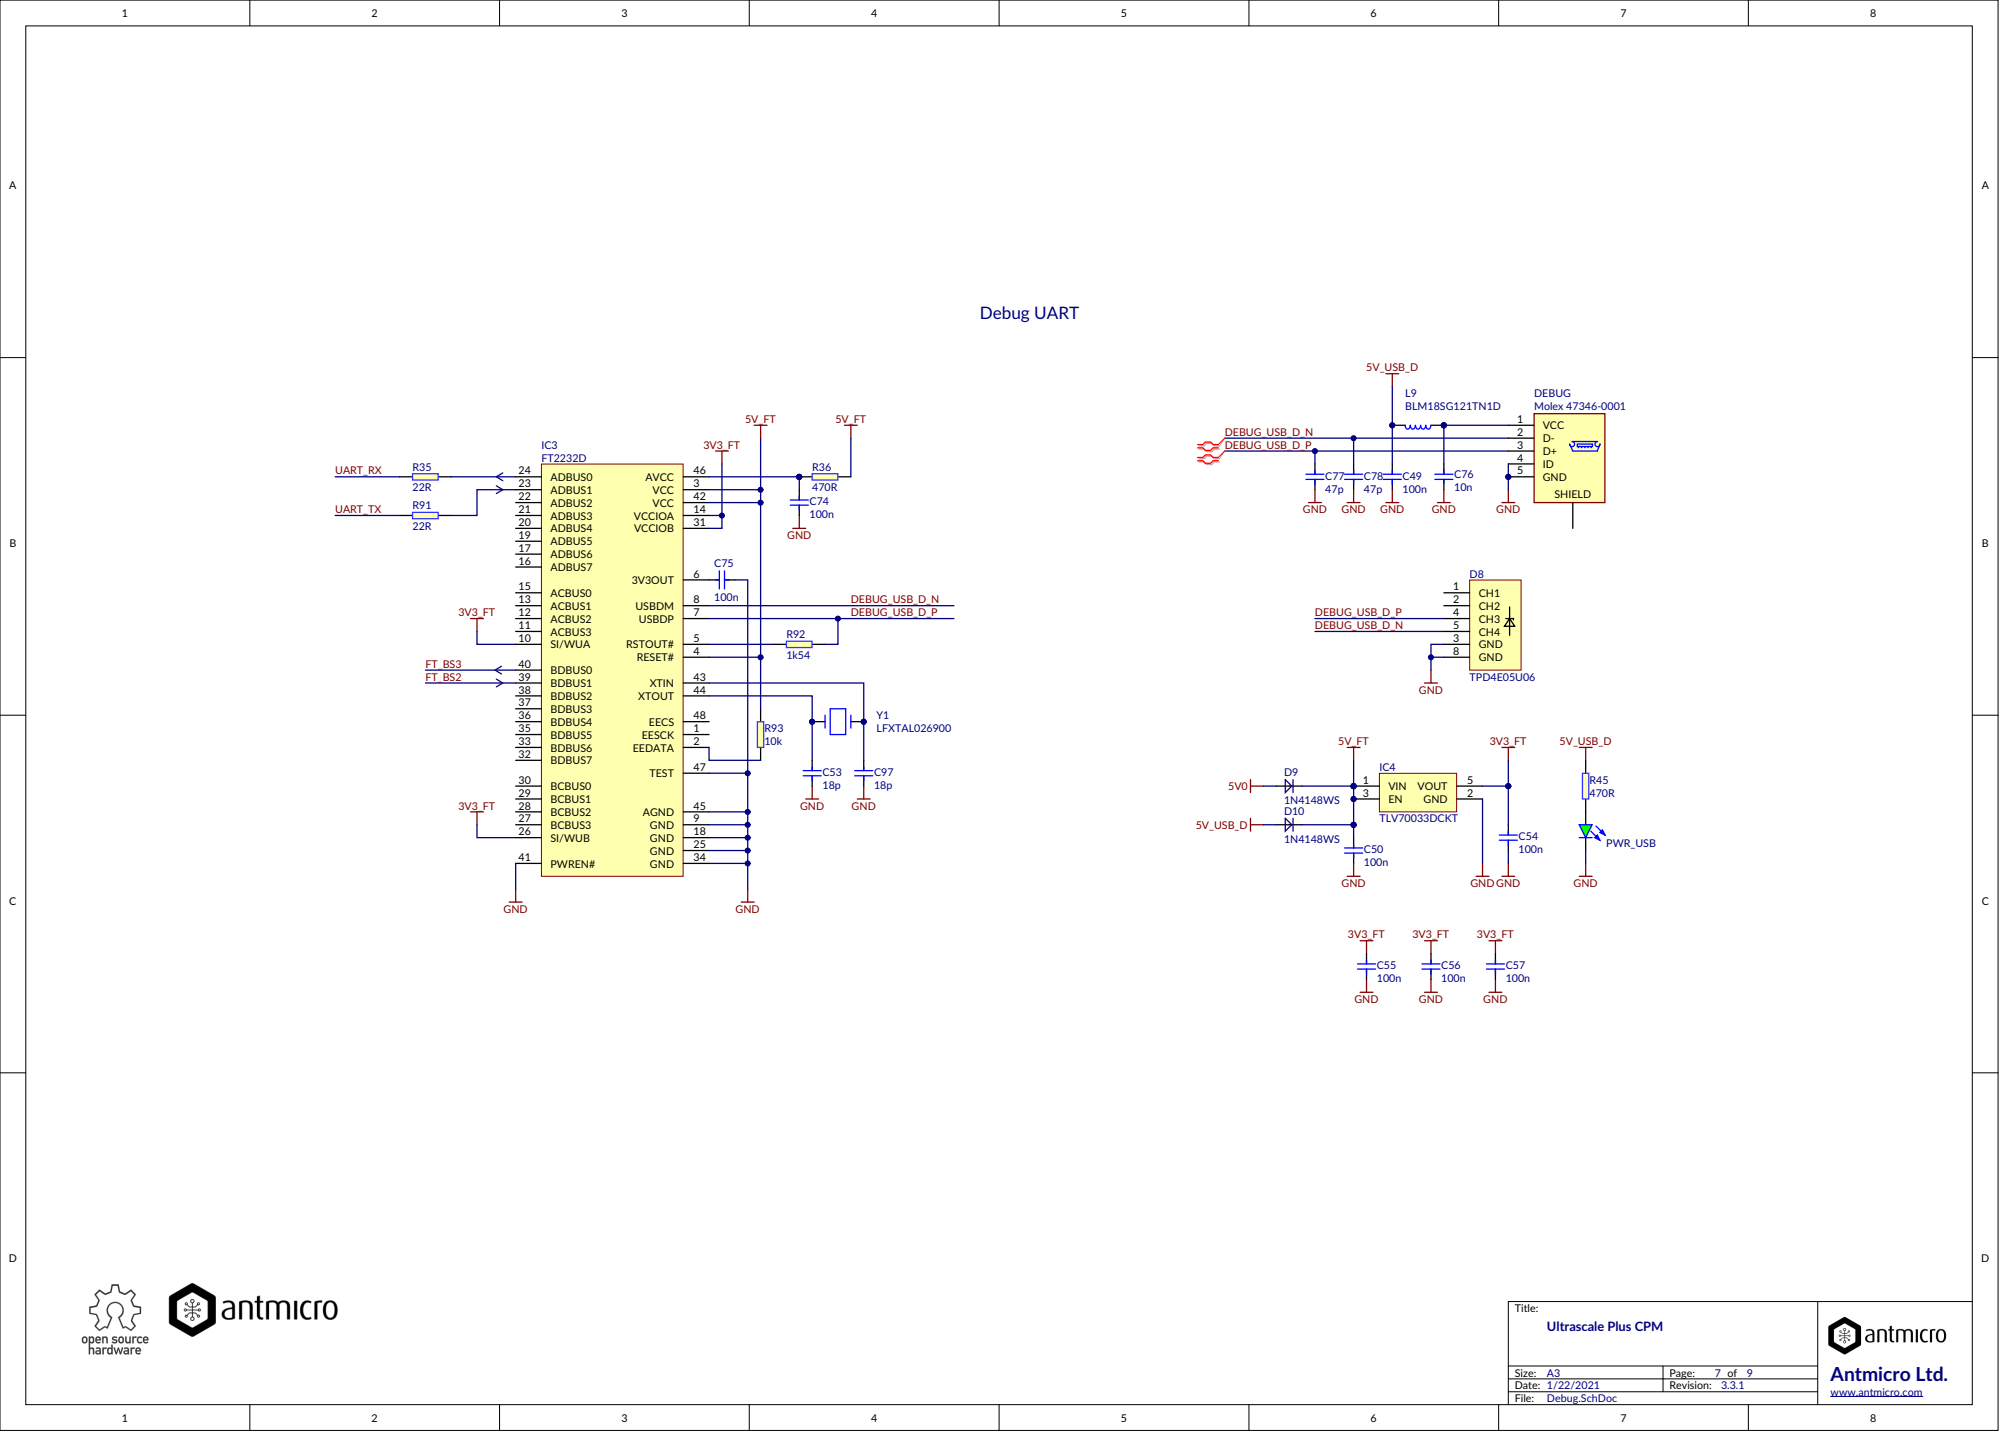
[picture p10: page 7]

BDBUS5 35 | 1
BDBUS6 33 | 2

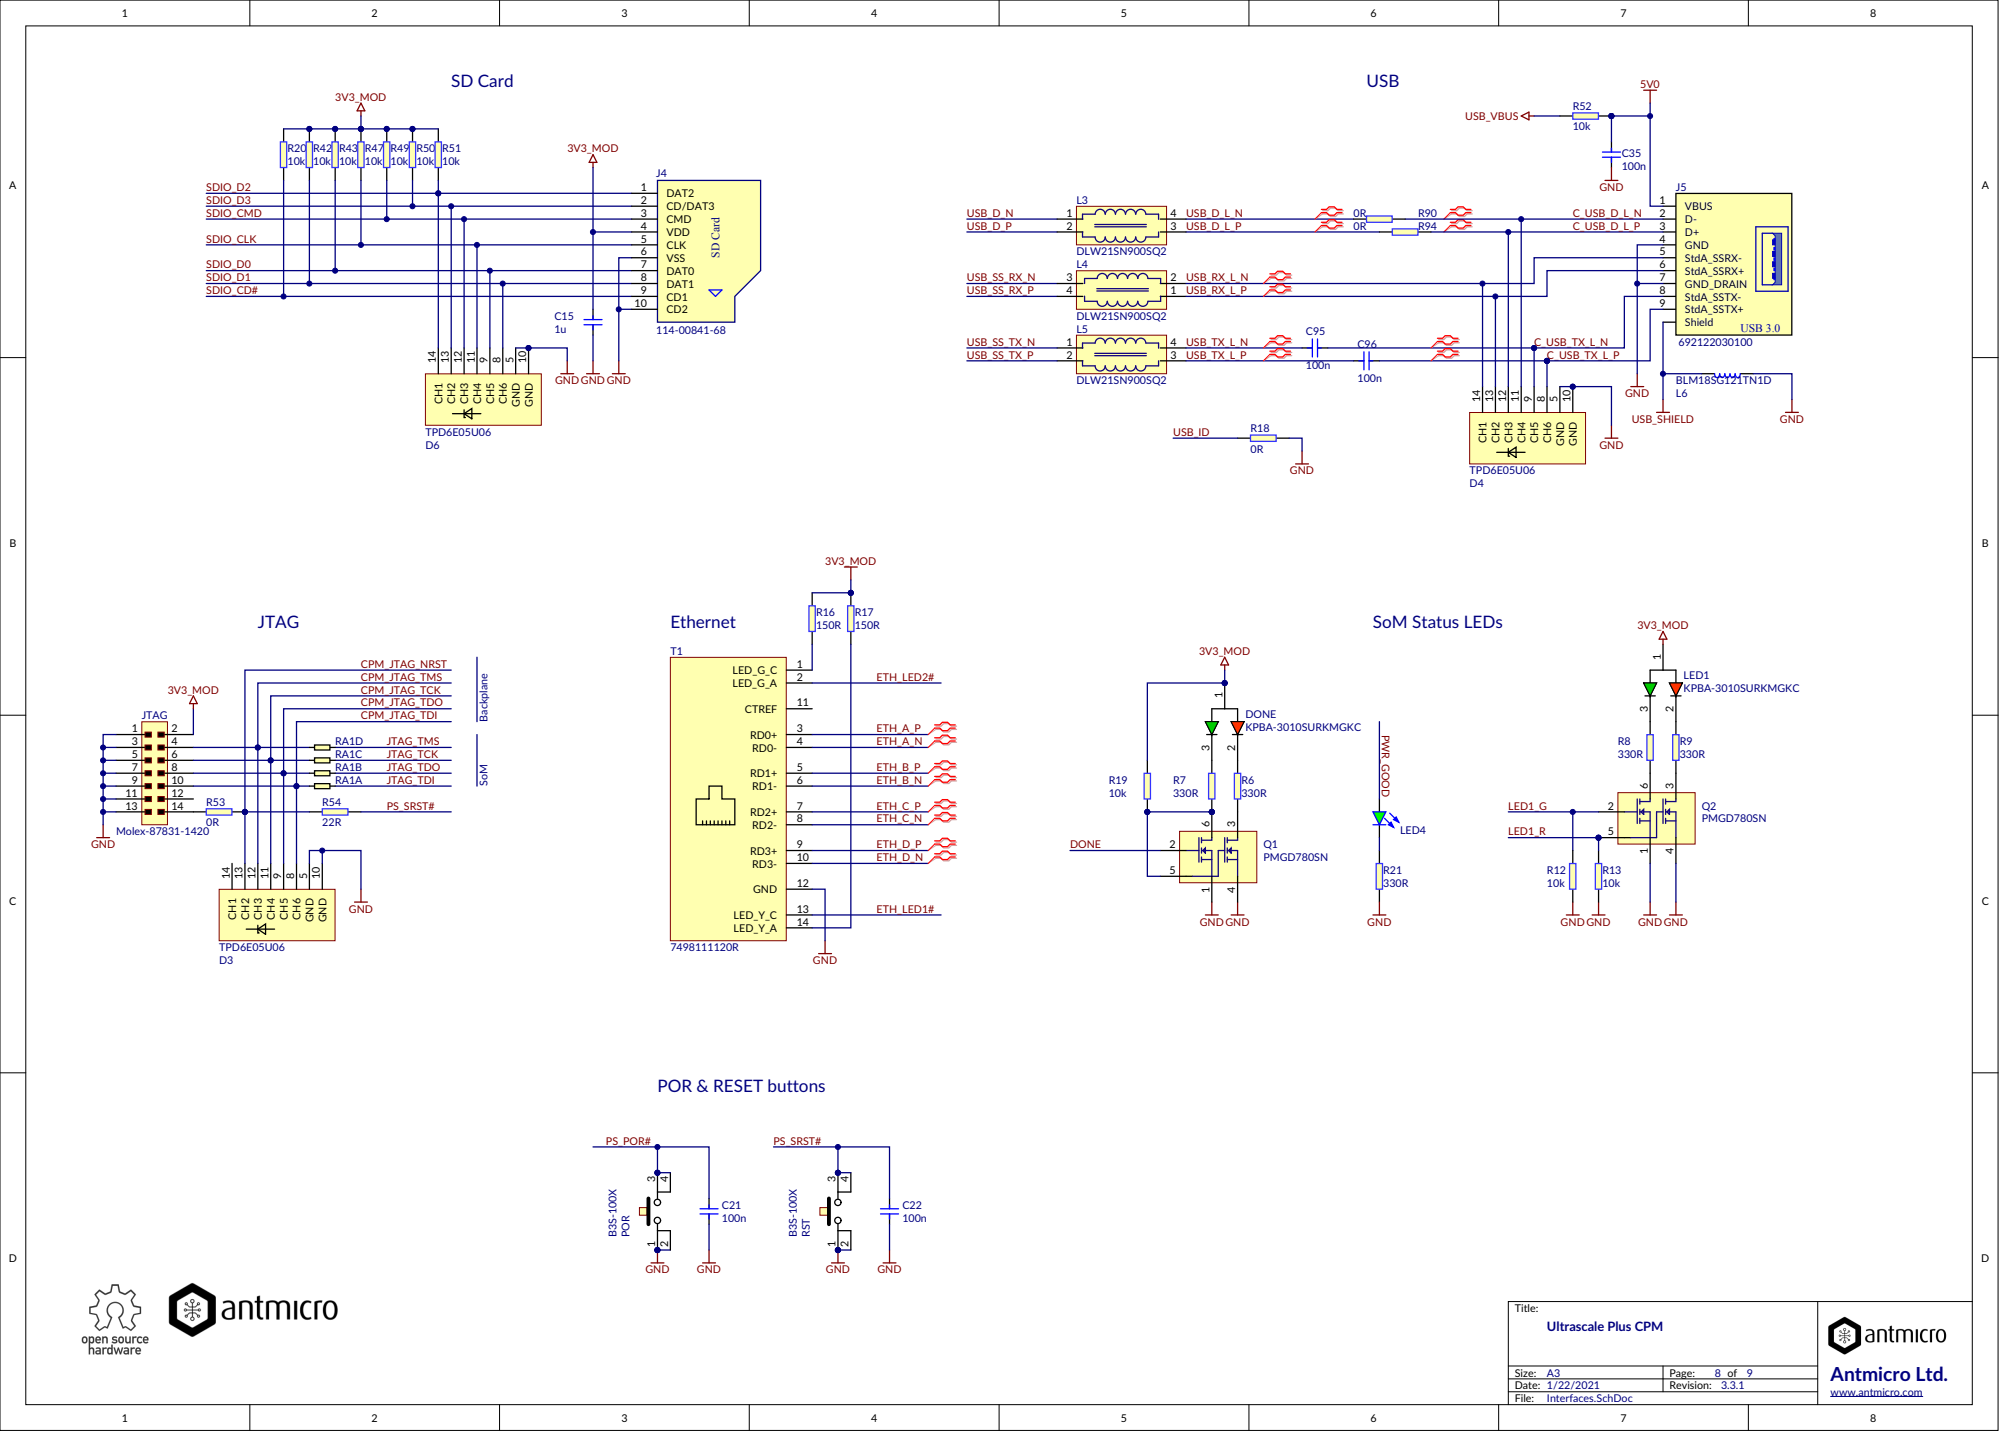
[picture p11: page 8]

C_USB_TX_L_P

5 | 6 | RA1C JTAG_TCK
7 | 8 | RA1B JTAG_TDO
9 | 10 | RA1A JTAG_TDI
11 | 12 R53 | R54 PS_SRST#
13 | 14

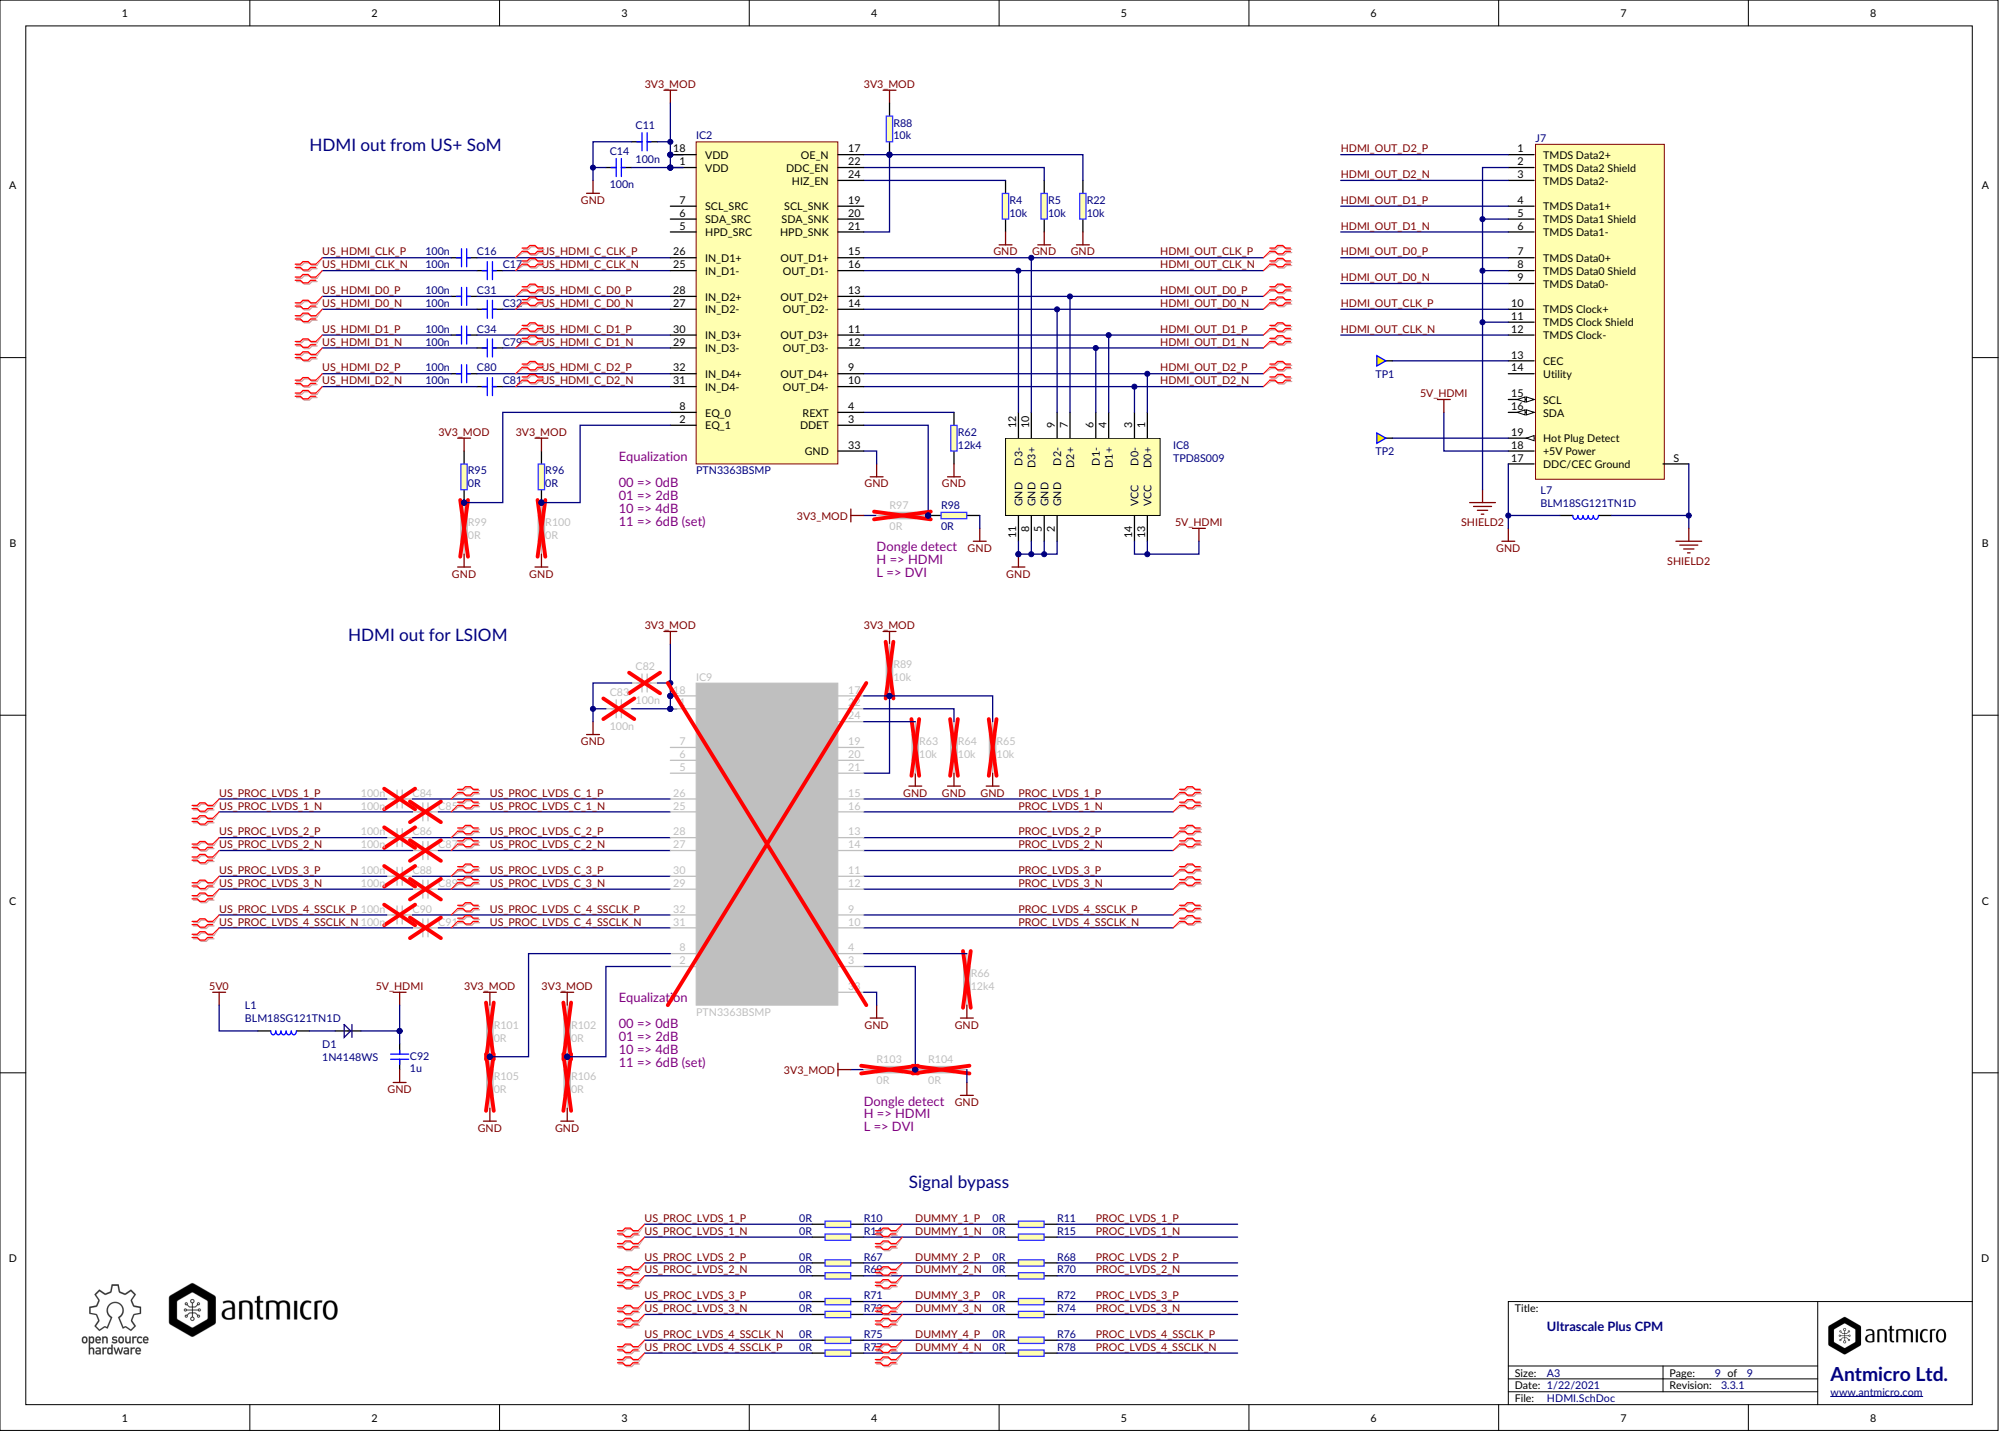
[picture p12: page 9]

HDMI out from US+ SoM

TMDS Clock- 12 CEC 13 Utility 14

HDMI out for LSIOM

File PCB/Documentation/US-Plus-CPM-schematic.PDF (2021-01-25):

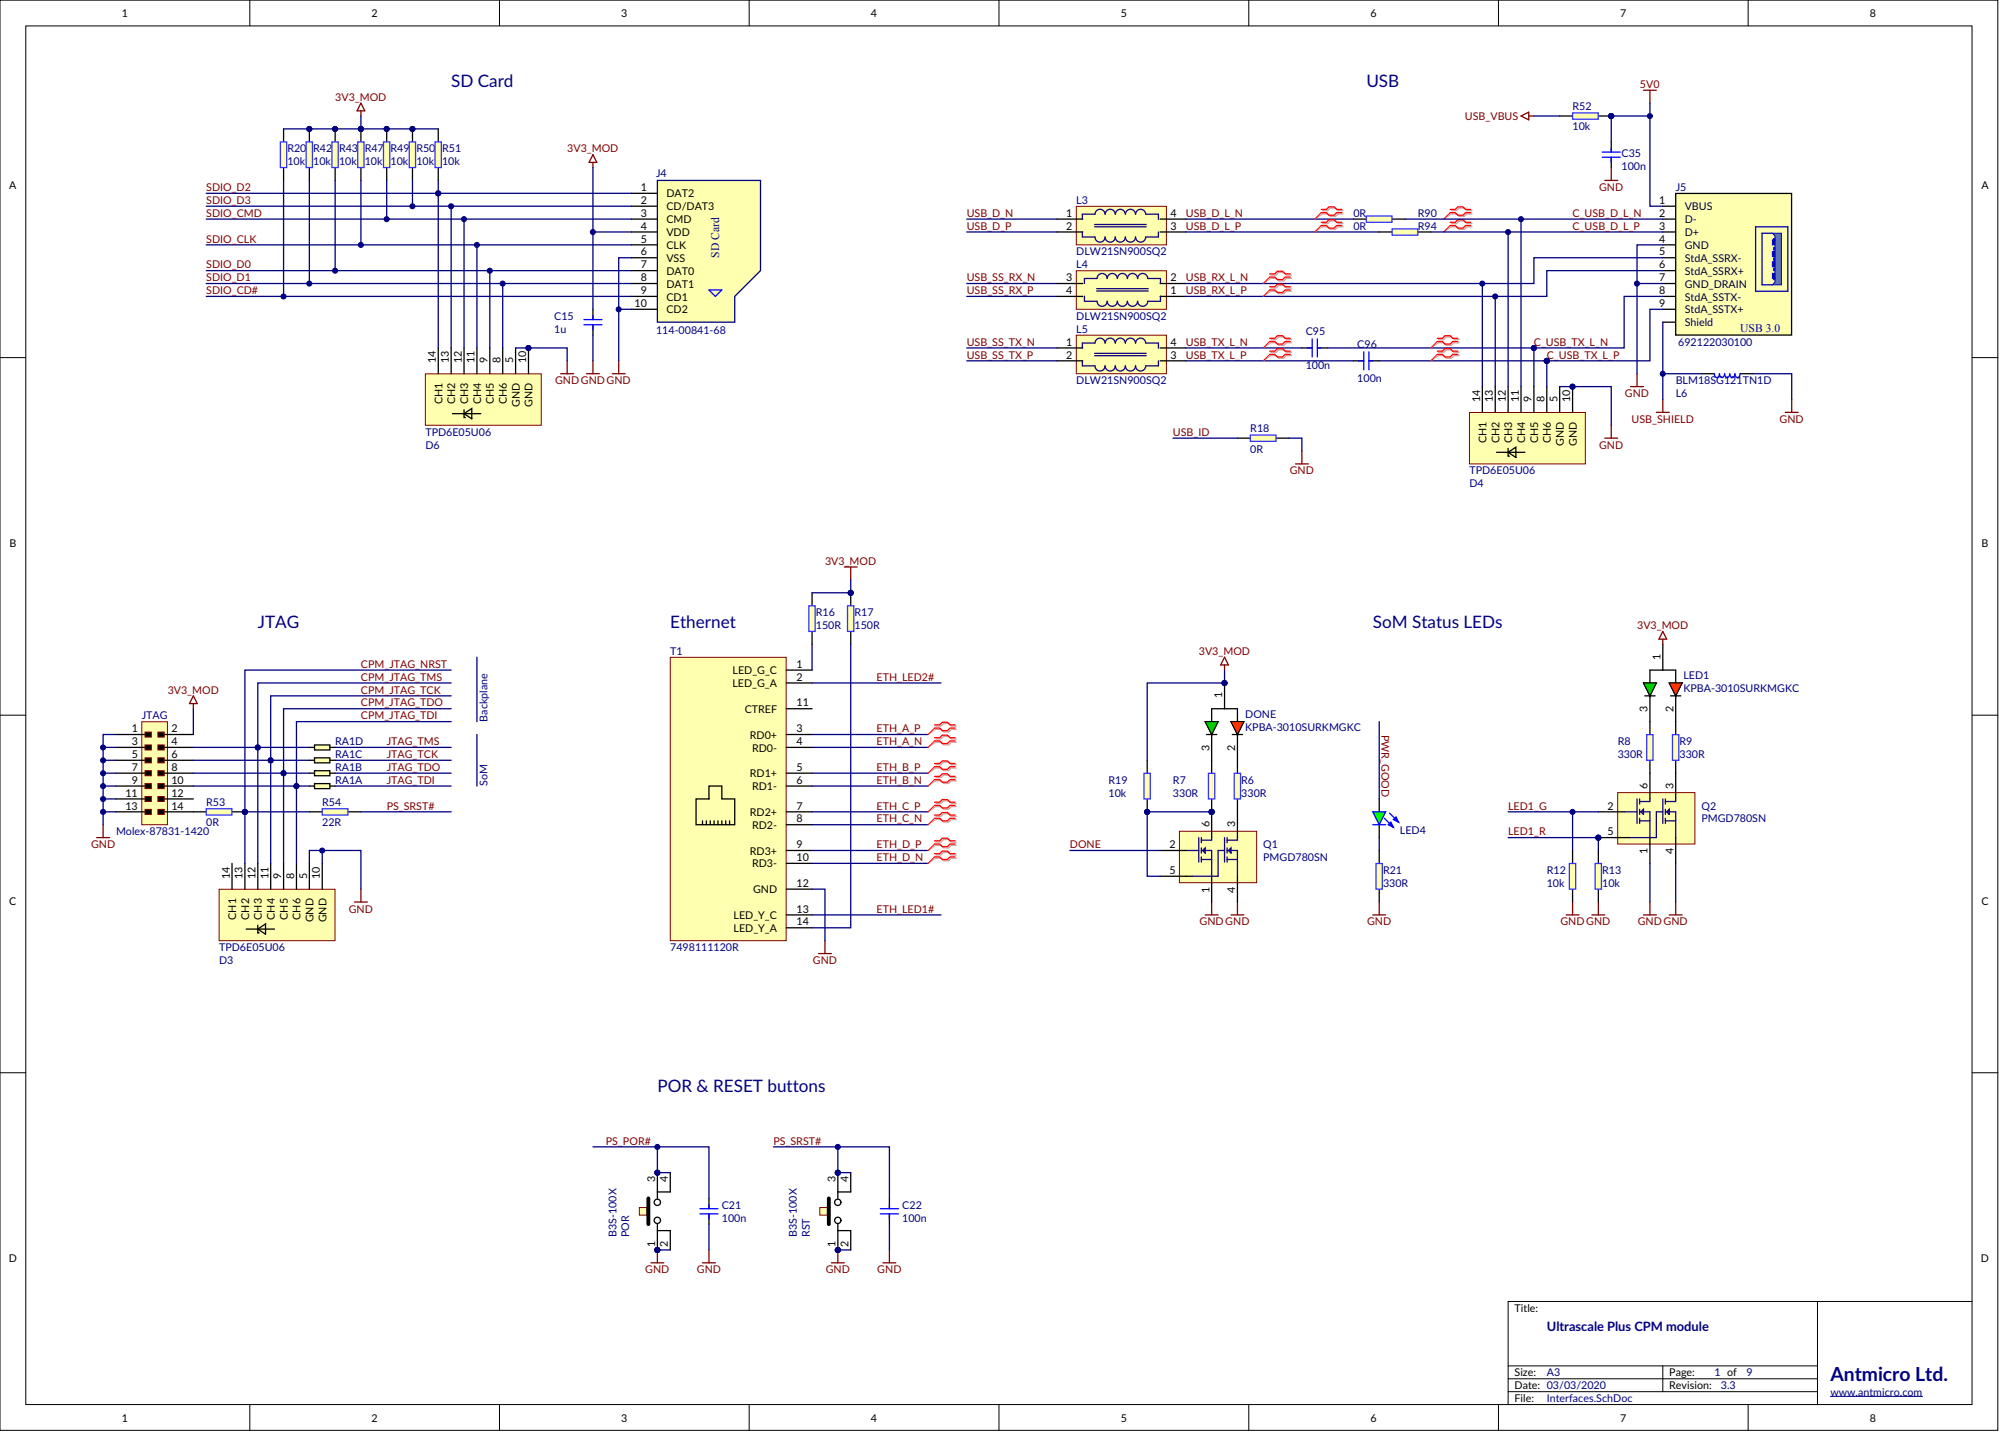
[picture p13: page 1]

C_USB_TX_L_P

5 | 6 | RA1C JTAG_TCK
7 | 8 | RA1B JTAG_TDO
9 | 10 | RA1A JTAG_TDI
11 | 12 R53 | R54 PS_SRST#
13 | 14

Title: Ultrascale Plus CPM module

Size: A3 | Page: 1 of 9 | Antmicro Ltd. www.antmicro.com
Date: 03/03/2020 | Revision: 3.3

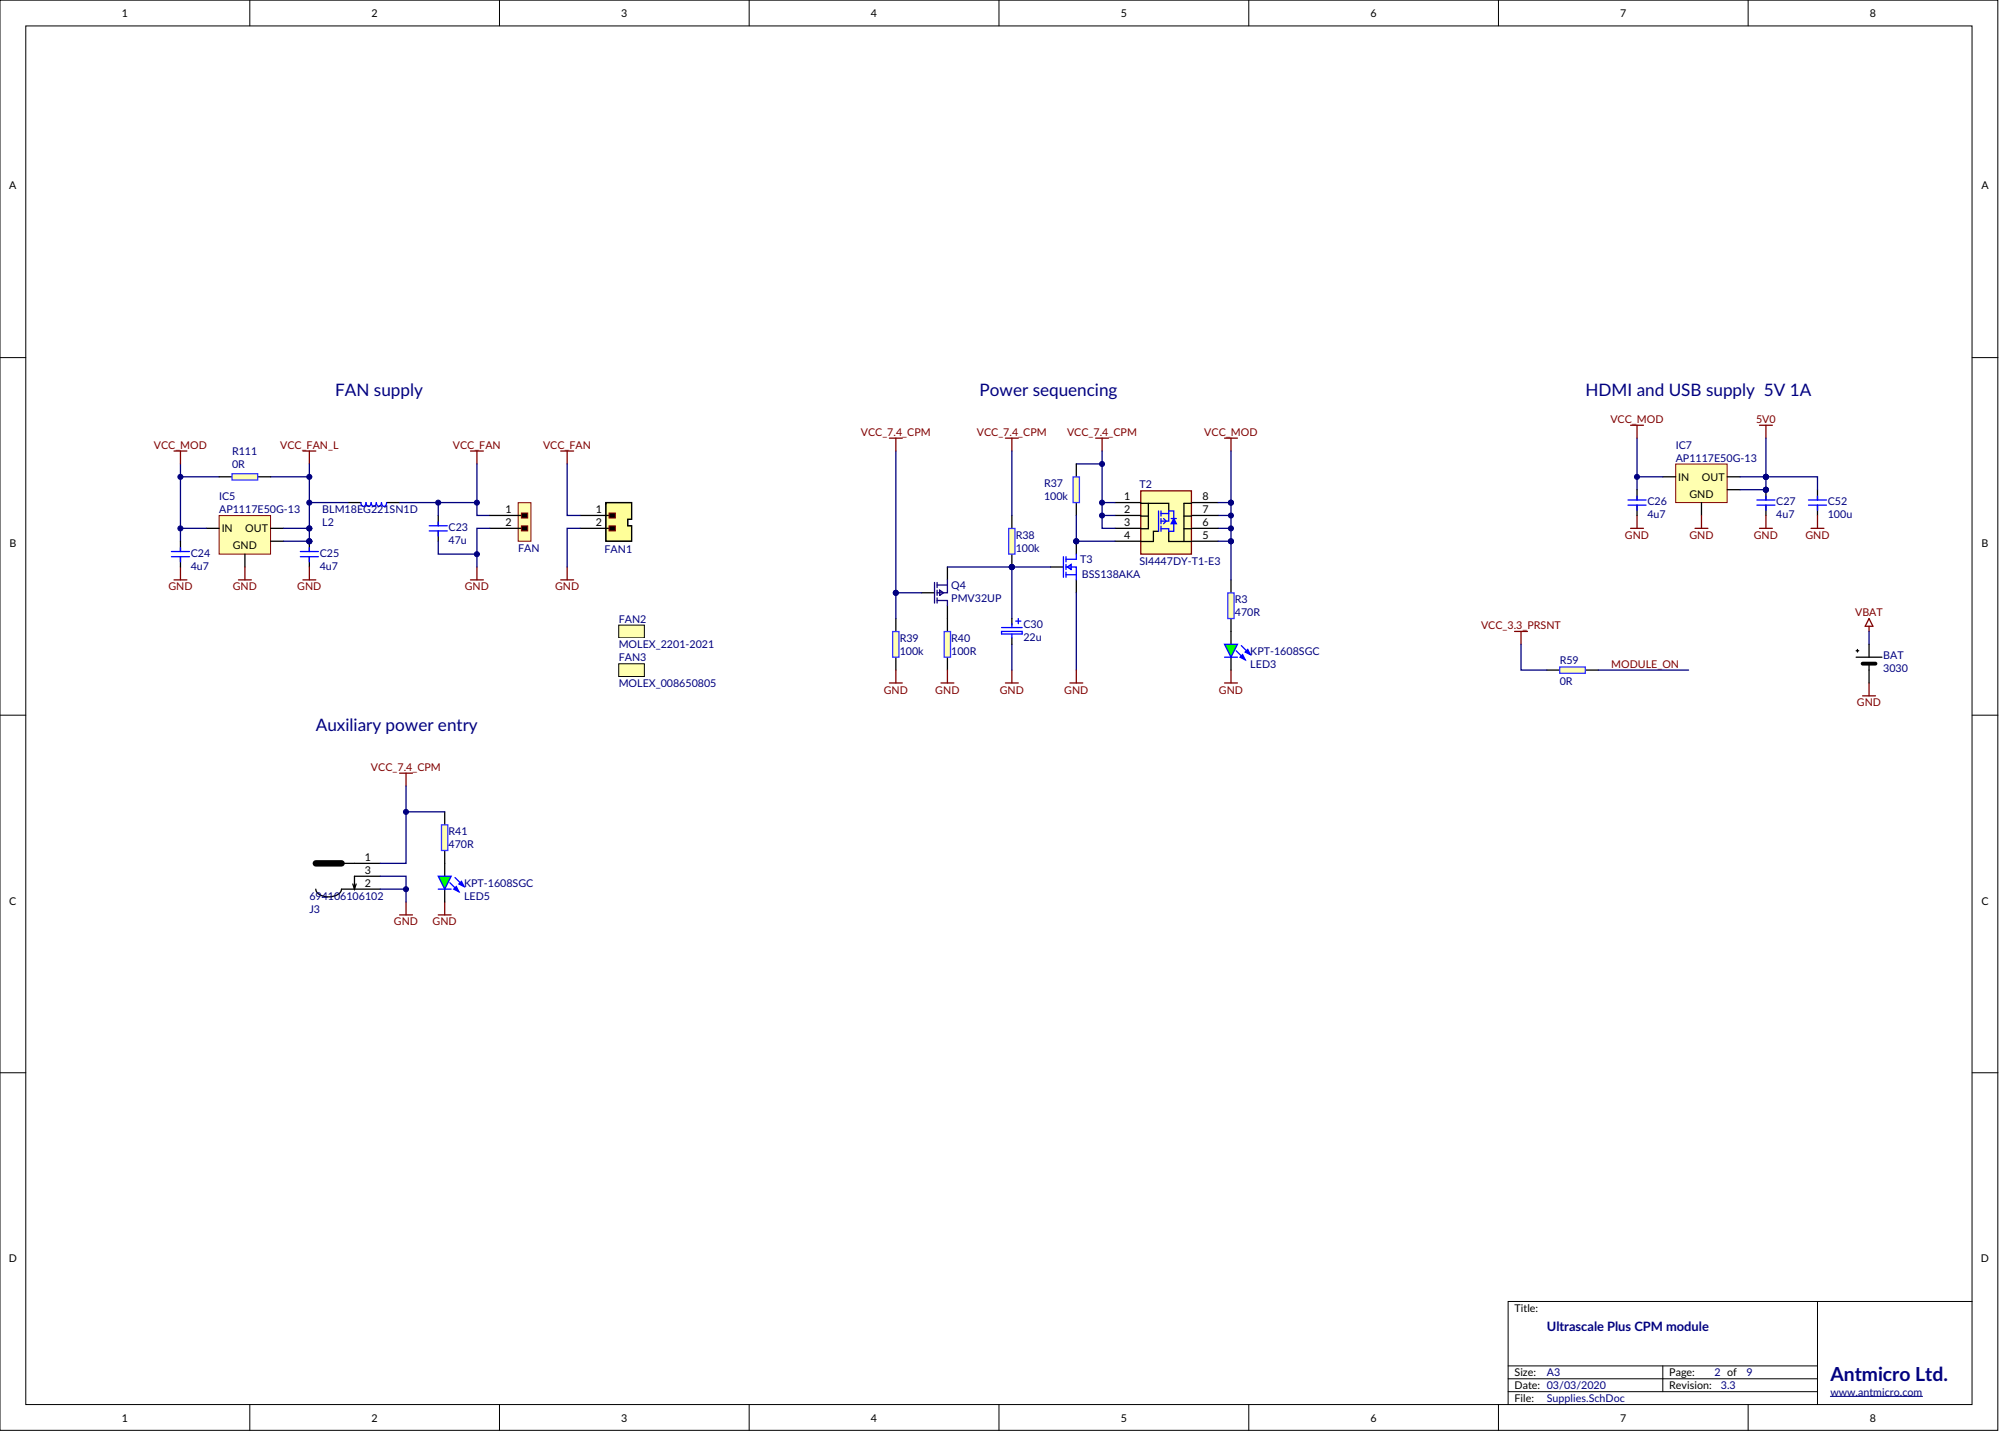
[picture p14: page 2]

Title:

A3 | Page: 2 of

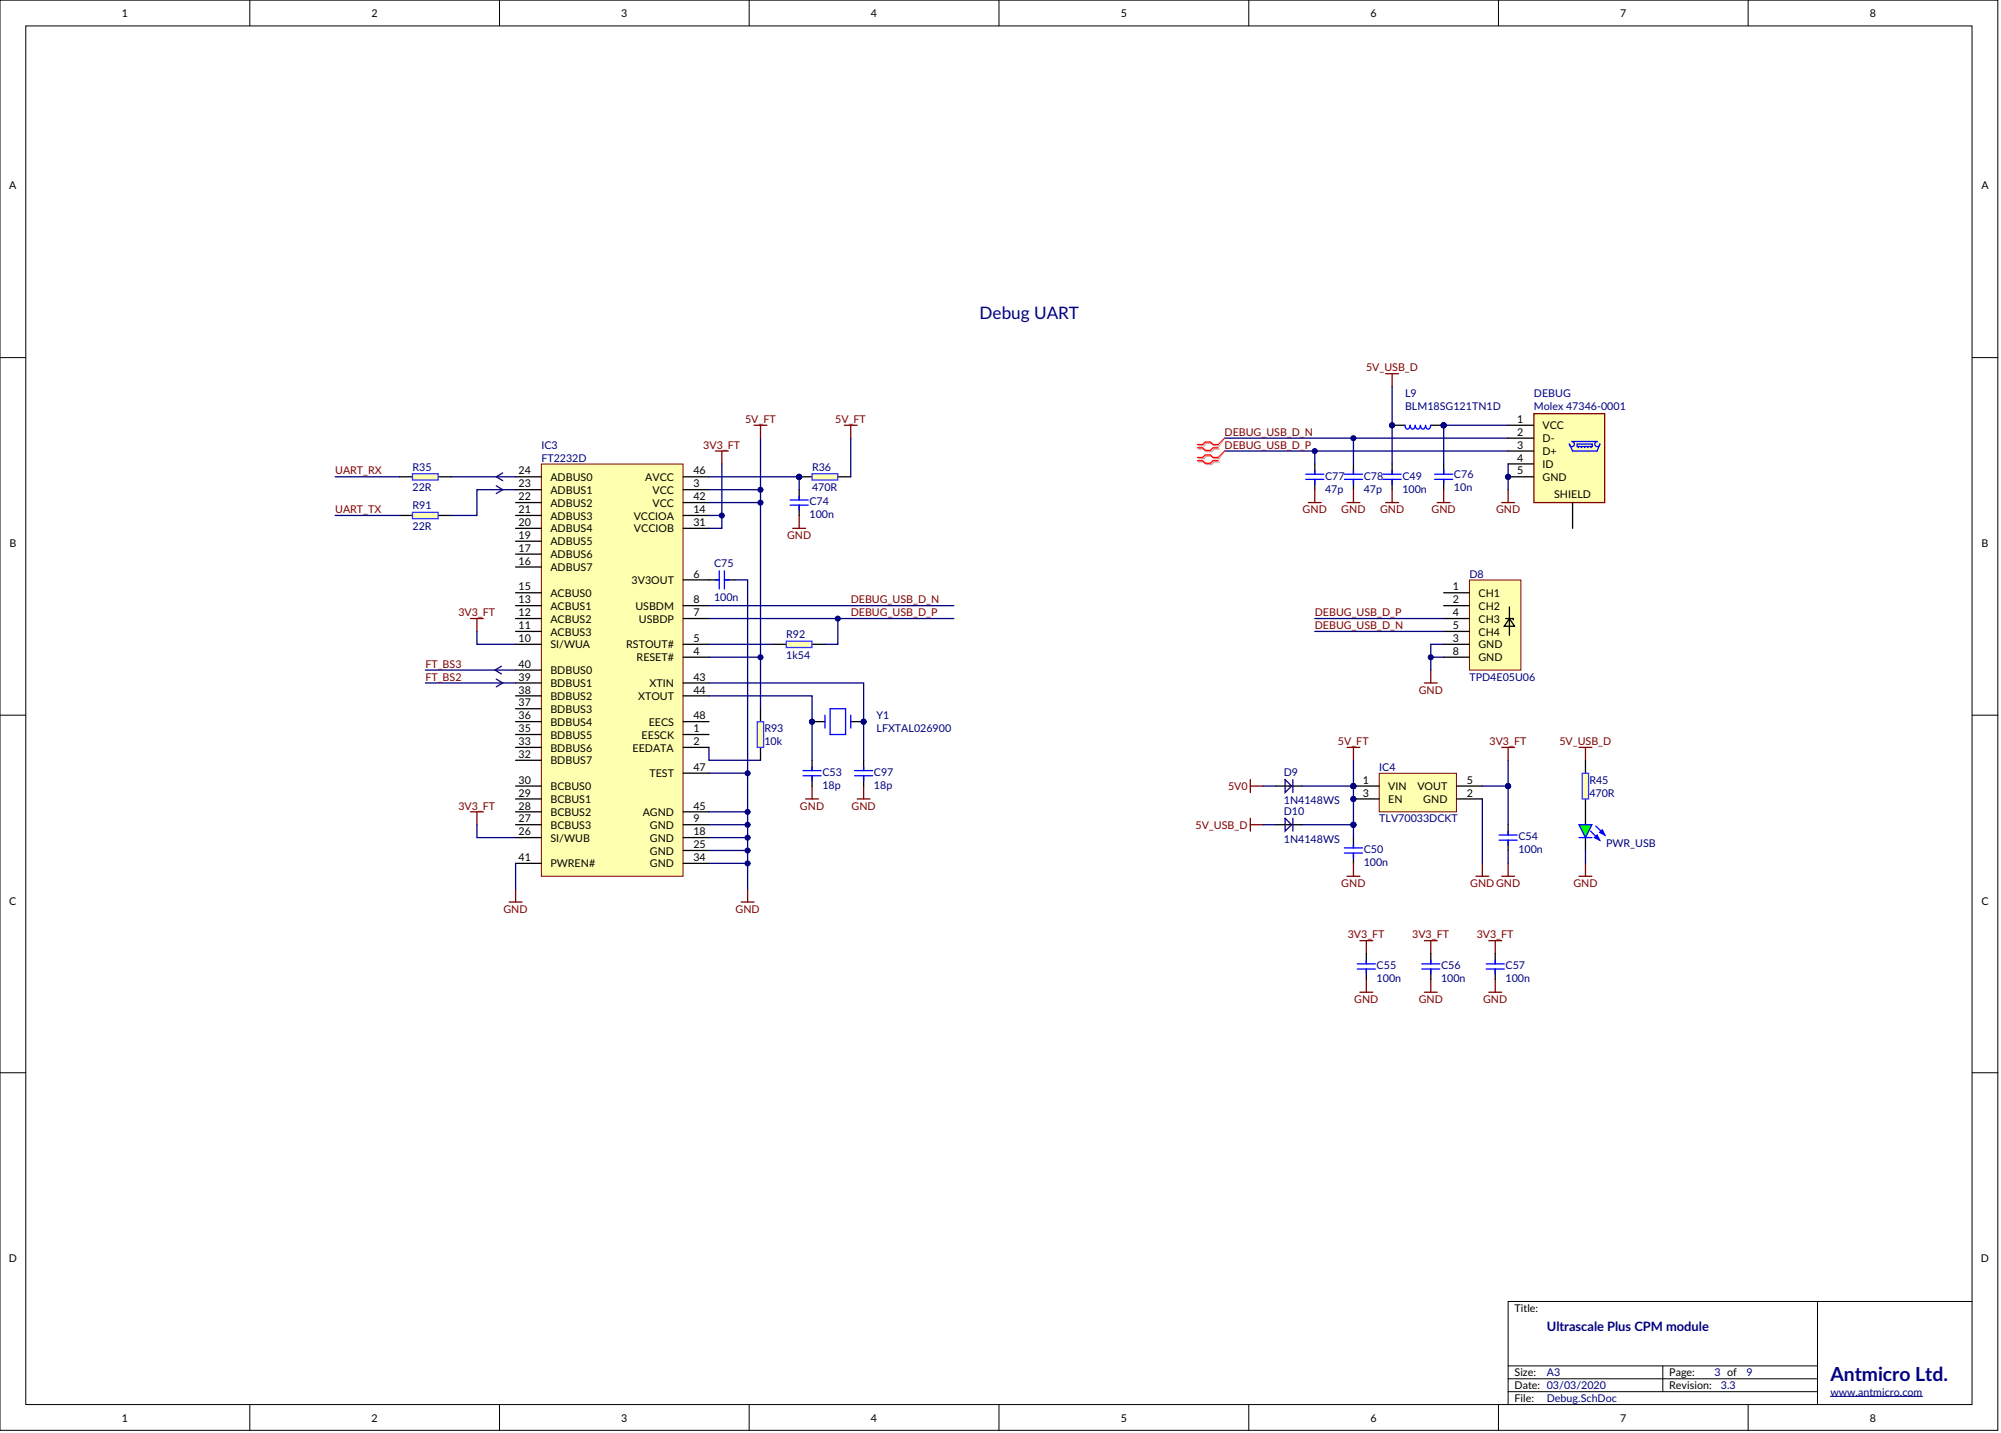
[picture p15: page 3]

BDBUS5 35 | 1
BDBUS6 33 | 2


HDMI out from US+ SoM

TMDS Clock- 12 CEC 13 Utility 14

HDMI out for LSIOM


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

D1+ 4
D1- 6

ML_LANE0_N 3 | R23

ML_LANE1_P 4 | DP_HP_C
ML_LANE1_N 6

GND 8


All S2 pairs tied to bank B65

42
44 46 48 50 52 54 56 58 60 62 64 66 68 70 72 74 76 78

All S1 pairs tied to bank B64

105
107


IO_P 87 IO_N 89 IO_P 91 IO_N 93 VIN_IO 95

PREPROC_LVDS_2_P PREPROC_LVDS_2_N PREPROC_LVDS_3_P PREPROC_LVDS_3_N PREPROC_LVDS_5_P PREPROC_LVDS_5_N PREPROC_LVDS_6_P PREPROC_LVDS_6_N

IO_P 101 IO_N 103 IO_P 105 IO_N 107 GND 109

IO_P 97 IO_N 99 IO_P 101 IO_N 103 GND 105

I2C_SCL 111

USB_DP 127 USB_DM 129 VBUS_HDP 131

ID_HDM 133 GND 135

USB_SSRX_P 137

USB_SSRX_N 141

Stencil for connector arrangement


MGT_TX_P 13 GND 15

MGT_TX_N 17 GND 19

MGT_TX_P 21 GND 23

MGT_TX_N 25 GND 27

MGT_TX_P 29 GND 31

MGT_TX_N 33 GND 35

MGT_TX_P 37 GND 39

MGT_TX_N 41 GND 43

SCLK_P 69 SCLK_N 71 GND 73

IO_P 75 IO_N 77 IO_P 79 IO_N 81 VOUT 83

IO_P 85 IO_N 87 SCLK_P 89 SCLK_N 91 GND 93

IO_P 95 IO_N 97 IO_P 99 IO_N 101 VOUT_3V3 103

SCLK_P 115 SCLK_N 117 IO_P 119 IO_N 121 VOUT 123

IO_P 125 IO_N 127 IO_P 129 IO_N 131 GND 133

IO_P 135 IO_N 137 IO_P 139 IO_N 141 VOUT_3V3 143

SCLK_P 151 SCLK_N 153 GND 155

IO_P 157 IO_N 159 IO_P 161 IO_N 163 VOUT 165

RSVD 167





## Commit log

2021-01-25 Add initial desgin files
    [Backplane-Connector.SchDoc, Debug.SchDoc, Display-Port.SchDoc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]
2021-01-25 Add documentation
    [US-Plus-CPM.PrjPcb]
2021-01-25 Remove empty parameter fields
    [Backplane-Connector.SchDoc, Debug.SchDoc, Display-Port.SchDoc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]
2021-01-25 Update MPN field for components
    [Backplane-Connector.SchDoc, Debug.SchDoc, Display-Port.SchDoc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]
2021-01-25 BOM cleanup
    [Backplane-Connector.SchDoc, Sensor-Connector.SchDoc, SoM-Connectors.SchDoc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]
2021-01-25 Update release number
    [Backplane-Connector.SchDoc, Debug.SchDoc, HDMI.SchDoc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]
2021-01-25 Minor fix
    [US-Plus-CPM.PrjPcb]
2021-01-25 Set OSHW template
    [US-Plus-CPM.PrjPcb]
2021-01-25 Add documentation for release 3.3.1
    [Ultrascale-Processing-Module-Rev.3.3.1-bom.csv]
